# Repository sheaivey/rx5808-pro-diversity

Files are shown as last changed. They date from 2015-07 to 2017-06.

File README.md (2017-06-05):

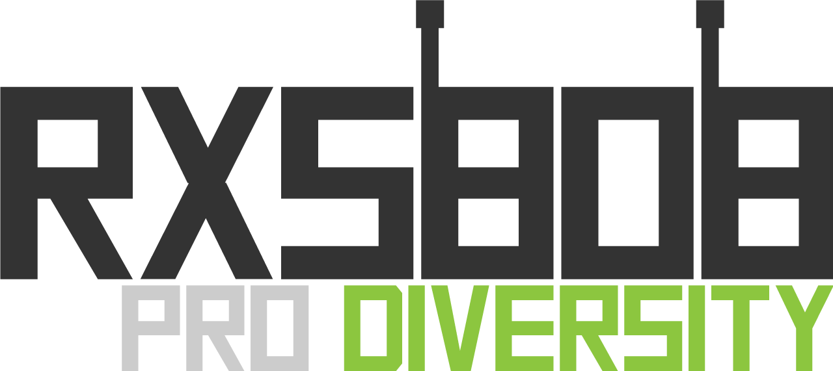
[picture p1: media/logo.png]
# 



This project is a fork of [rx5808-pro](https://code.google.com/p/rx5808-pro/) with support for diversity and much more.

Manufactured version of this project can be found at [La Forge FPV](http://www.laforgefpv.com)

The code is also backward compatible with the original rx5808-pro schematic minus diversity, dip switch mode and TV_Out. For details on updating click [here](/docs/diy-arduino-nano.md).

# Table of Contents
1. [Releases](#releases)
2. [Features](#features)
3. [Overview](#overview)
4. [Hardware](#hardware)
5. [Firmware](#firmware)
6. [Contributing](#contributing)
7. [License](#license)

# Releases
The latest release can be found here. [Latest Releases](https://github.com/sheaivey/rx5808-pro-diversity/releases)

# Features
- **User control** - 3 Button navigation, up, down, select.
- **Manual Mode** - Set channel manual
- **Search Mode** - Search next channel based on RSSI
- **Band Scanner** - Print spectrum of all 48 channels
- **Auto Save** - Saves settings after a few seconds of inactivity.
- **Beeper** - Acoustic feedback on important actions
- **RSSI Graph** - Running history of RSSI readings.
- **Diversity** - Receiver select and monitor.
- **Led Status** - Power, button pressed, active antenna.
- **Race Band & L-Band** - Total of 48 supported channels.
- **Backward Compatibility** - Use this code with your existing setup.
- **OLED Display** - Use a 128x64 OLED.
- **Setup Menu** - Creating changing settings (RSSI Calibration).

# Overview
Please watch the following video giving a detailed overview of the latest v2.0 release.

<p align="center">
    
</p>

1. **Auto Scan** - Scans all bands until a signal with good signal strength is found.
2. **Manual Mode** - Will hold on a manually selected channel.
3. **Band Scanner** - Scans all bands and presents them with a signal strength bar graph.
5. **Settings Menu** - Saves last used channel and mode for next power cycle. This is also where you enter RSSI calibration mode.
    1. **Calibrate RSSI** - Calibrate the min and max RSSI values.

#### Initial Setup
When powering on for the first time it is best to calibrate your RSSI modules. No two modules have the same RSSI min and max readings. To calibrate follow these steps below. You can repeat this process as many times as needed.

1. Go to the settings menu and follow the calibrate RSSI steps on the screen.

# Hardware
#### Manufactured
If you are not looking to build your own hardware you can purchase manufactured versions from the following companies.

1. **[La Forge FPV](http://www.laforgefpv.com/vrx-pro)** - VRX-PRO
  - Designed by Shea Ivey
  - All Current Hardware versions.
2. Realacc - rx5808-pro-diversity
  - All current hardware versions.
3. FuriousFPV - True-D
  - V2.0 and earlier

#### DIY

This project is centered around the RX5808 5.8GHz receiver module which can be found at a number of online stores. The original rx5808-pro schematic has been modified to incorporate the diversity setup. Additional LEDs have also been added to show the active receiver.

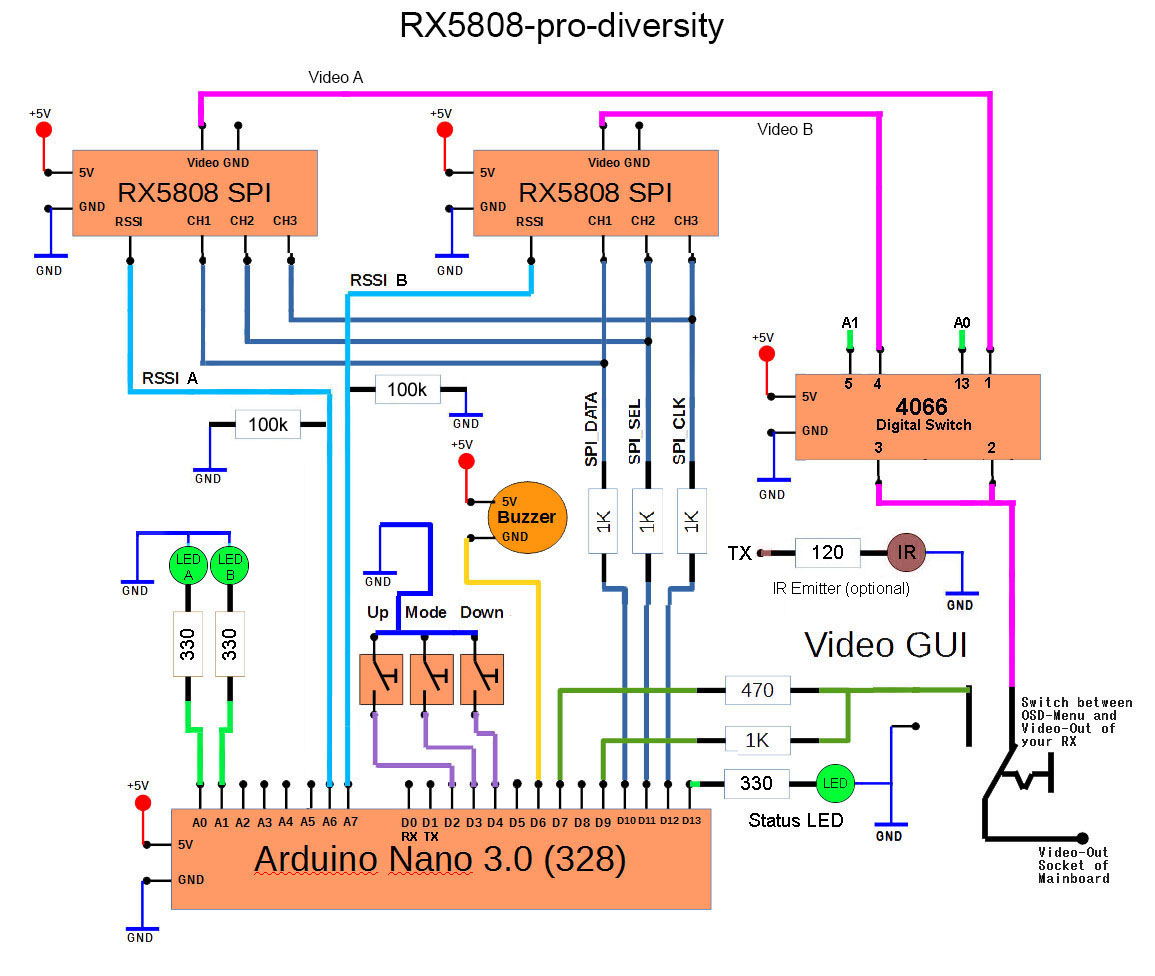
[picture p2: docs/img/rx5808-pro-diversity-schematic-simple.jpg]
diversity simple schematic


For more information on specific hardware implementations:

1. [DIY Simple - Arduino Nano](/docs/diy-arduino-nano.md)
1. [DIY Intermediate - Custom Board (T-Box)](/docs/diy-through-hole-board.md)
2. [DIY Advanced - Custom Board](/docs/diy-custom-board.md)
1. [OLED Version - Arduino Nano](/docs/oled-arduino-nano.md)
3. [rx5808 SPI modification](/docs/rx5808-spi-mod.md)
6. [Voltage Monitoring](/docs/voltage-monitoring.md)

# Firmware
The firmware is constantly being improved please refer to the release history for more detailed information on improvements.
[Release History](https://github.com/sheaivey/rx5808-pro-diversity/releases)

# Contributing
Any contributions are welcome!

Please follow [CONTRIBUTING.md](CONTRIBUTING.md) for standard practices regarding this repo.

## Recognition
- SPI driver based on fs_skyrf_58g-main.c Written by Simon Chambers
- TVOUT by Myles Metzel
- Scanner by Johann Hermen (der-Frickler.net)
- Initial 2 Button version by Peter (pete1990)
- Refactored and GUI reworked by Marko Hoepken
- Universal version my Marko Hoepken
- Diversity Receiver Board and GUI improvements by Shea Ivey
- Adding Race Band by Shea Ivey
- Separating Display concerns for TVOut and OLED by Shea Ivey
- Adding Setup Menu by Shea Ivey
- DIY Throughole board and documentation. by RCDaddy
- Voltage monitoring by kabturek
- v2.0 Firmware Overhaul by @Knifa

# License
## Code
The code is distrubuted under the [MIT license](LICENSE.md).

## Logo
The logo is distributed under the [Creative Commons Attribution 4.0 International](http://creativecommons.org/licenses/by/4.0/) license.

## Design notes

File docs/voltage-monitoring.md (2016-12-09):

#Voltage Monitoring
You can monitor voltages of the attached battery by using any of the arduino analog pins and a voltage divider to lower the voltage to safe levels (5v). You have to enable (uncomment) "#define USE_VOLTAGE_MONITORING" and change "#define VBAT_PIN A2" to the pin you will be using.

Lets take the [DIY Advanced - Custom Board](/docs/diy-custom-board.md) as an example. Atmega 328 has 8 analog inputs (or 6 if youre using the DIP package) - A4 and A5 are used for controlling the oled if you're using one, A6 and A7 are used for measuring RSSI. There are no more easily accesible analog pins on the advanced board - you will have to solder a wire directly to the processor pins. The default pin depends on the screen output - A2 for oled ( on the edge of atmega chip - easier to hand solder) or A4 when TVout is used - use pad SDA on custom board.

Now you have to create a simple voltage divider circuit - let's assume a 3S battery (12.6V max) and use standard resistor values - using R1 = 5.6K and R2 = 3.3K will allow us to connect a battery with voltage of around 13.4V (keep in mind the resistors have 5% tolerance so it's good to have some margin). The cap is optional - it will smooth the voltage readings.
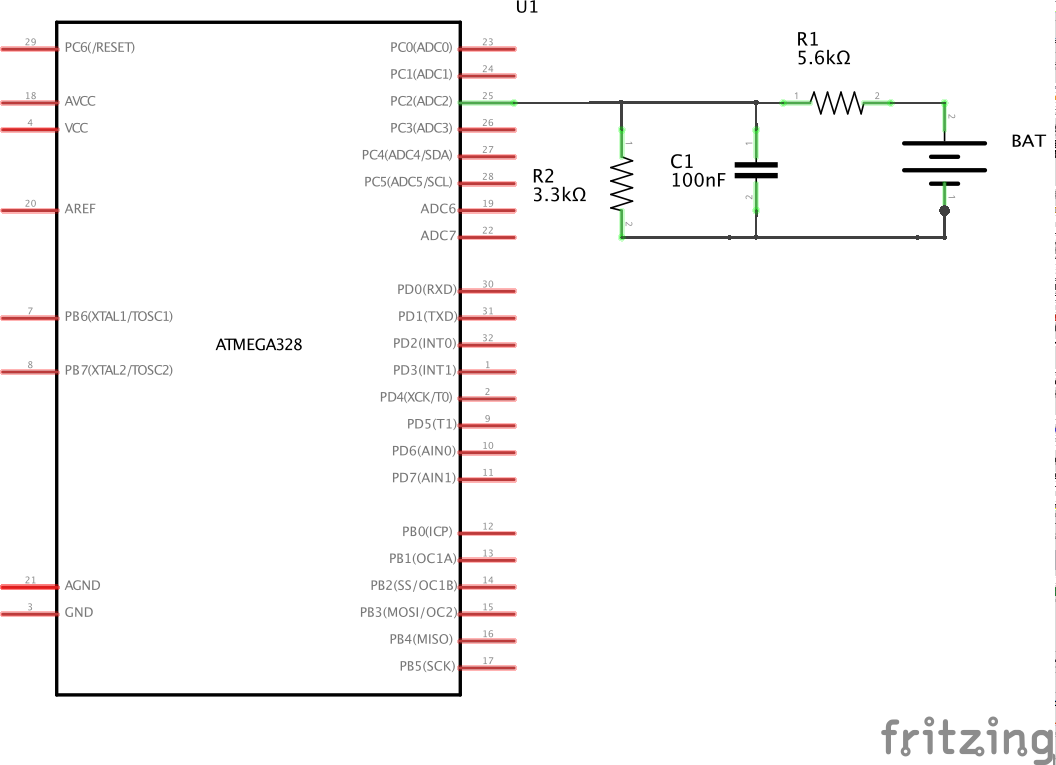
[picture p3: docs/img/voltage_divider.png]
voltage divider


Here is a picture of a voltage divider on the advanced board using an OLED:
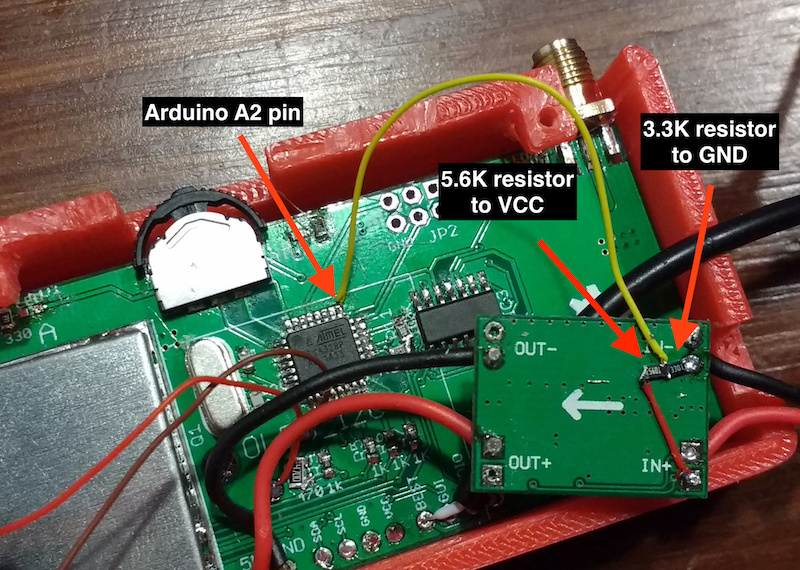
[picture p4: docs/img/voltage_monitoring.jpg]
voltage divider


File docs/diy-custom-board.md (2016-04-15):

#DIY Advanced - Custom Board
This requires ordering a board from [https://oshpark.com/shared_projects/7J17i6at](https://oshpark.com/shared_projects/7J17i6at)
No bootloader is nessissary with this board. Program the board using the SPI breakout pins. (Select Arduino Pro Mini 5v 328 as the board)

####BOM
- 4x 1K ohm resistor 0805 [Mouser](http://www.mouser.com/Search/ProductDetail.aspx?R=ERJ-6ENF1001Vvirtualkey66720000virtualkey667-ERJ-6ENF1001V)
- 1x 470 ohm resistor 0805 [Mouser](http://www.mouser.com/Search/ProductDetail.aspx?R=ERJ-6ENF4700Vvirtualkey66720000virtualkey667-ERJ-6ENF4700V)
- 3x 330 ohm resistor 0805 [Mouser](http://www.mouser.com/Search/ProductDetail.aspx?R=ERJ-6ENF3300Vvirtualkey66720000virtualkey667-ERJ-6ENF3300V)
- 2x 100k ohm resistor 0805 [Mouser](http://www.mouser.com/Search/ProductDetail.aspx?R=ERJ-6ENF1003Vvirtualkey66720000virtualkey667-ERJ-6ENF1003V)
- 2x 22pf capacitor 0805 [Mouser](http://www.mouser.com/Search/ProductDetail.aspx?R=C0805C220J5GACTUvirtualkey64600000virtualkey80-C0805C220J5G)
- 1x 16.0000mhz crystal [Mouser](http://www.mouser.com/Search/ProductDetail.aspx?R=FOXSLF%2f160-20virtualkey55910000virtualkey559-FOXS160-20-LF)
- 2x rx5808 receiver with [spi mod](rx5808-spi-mod.md)
- 2x Blue LEDs 0805 [Mouser](http://www.mouser.com/Search/ProductDetail.aspx?R=LTST-C170KRKTvirtualkey57820000virtualkey859-LTST-C170KRKT)
- 1x Red LED 0805 [Mouser](http://www.mouser.com/Search/ProductDetail.aspx?R=LTST-C170TBKTvirtualkey57820000virtualkey859-LTST-C170TBKT)
- 1x [Navigation switch](https://www.sparkfun.com/products/8184) or [ebay](http://www.ebay.com/itm/231618098407?ul_noapp=true)
- 2x SMA Connector [Mouser](http://www.mouser.com/search/ProductDetail.aspx?R=0virtualkey0virtualkey132322)
- 1x 4066D SO14 digital switch chip SMD [Mouser](http://www.mouser.com/Search/ProductDetail.aspx?R=74LVC4066D%2c118virtualkey66800000virtualkey771-74LVC4066D-T)
- 1x MEGA 328P TQFP [Mouser](http://www.mouser.com/search/ProductDetail.aspx?R=0virtualkey0virtualkeyATMEGA328P-AU)
- 1x Active Buzzer (Optional)
- 1x OLED 128x64 display I2C (5v tollerant) (Optional - If you don't want to do TV_Out)

[Mouser cart](http://www.mouser.com/ProjectManager/ProjectDetail.aspx?AccessID=9f6e677f02) with everything but rx5808, navigation switch and optional parts.

####Schematic
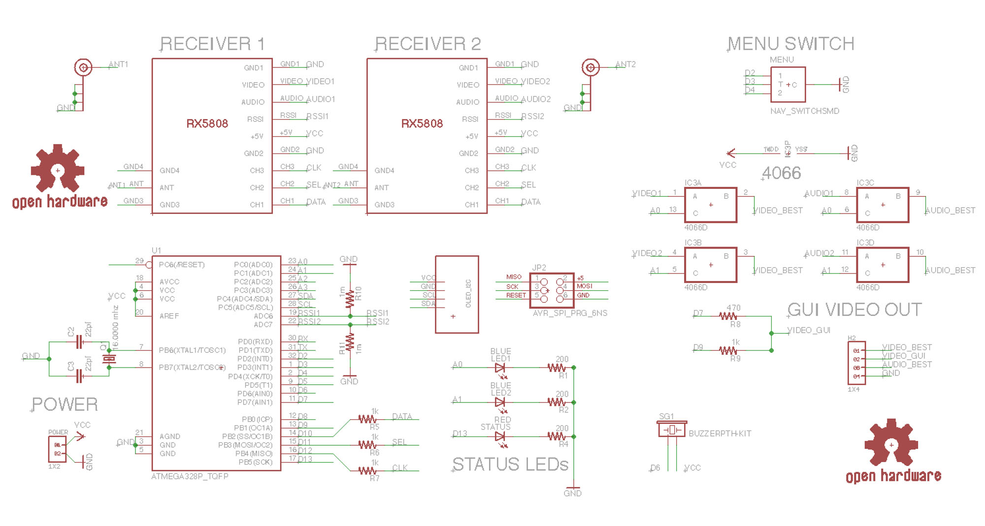
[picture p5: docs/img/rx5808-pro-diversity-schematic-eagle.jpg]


####Board
Silk:
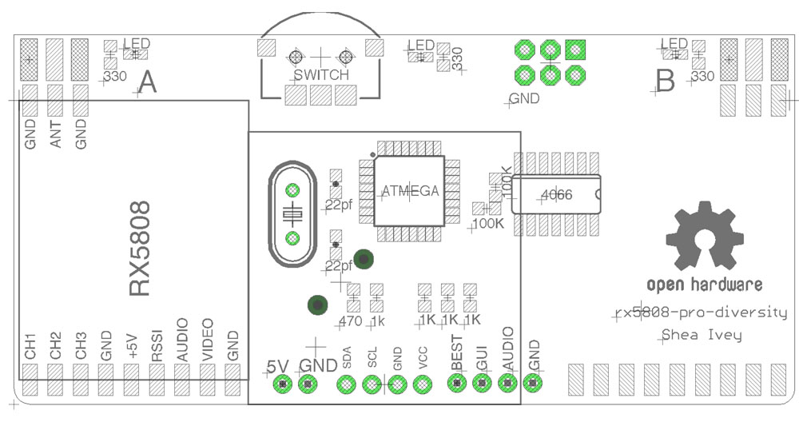
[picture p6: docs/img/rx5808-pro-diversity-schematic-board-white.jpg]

Top:
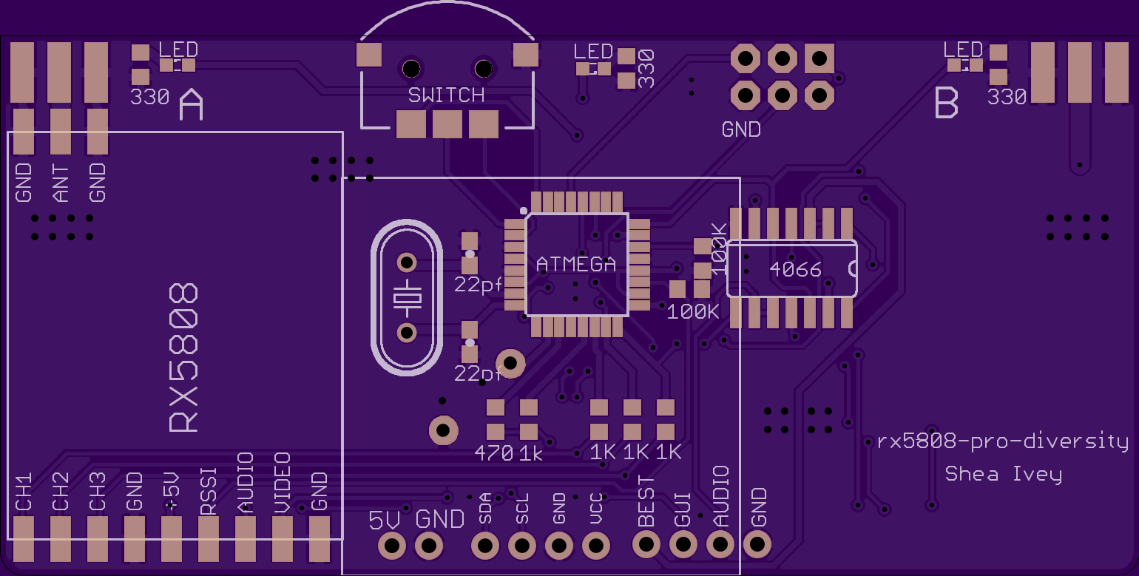
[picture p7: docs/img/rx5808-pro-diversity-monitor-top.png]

Bottom:
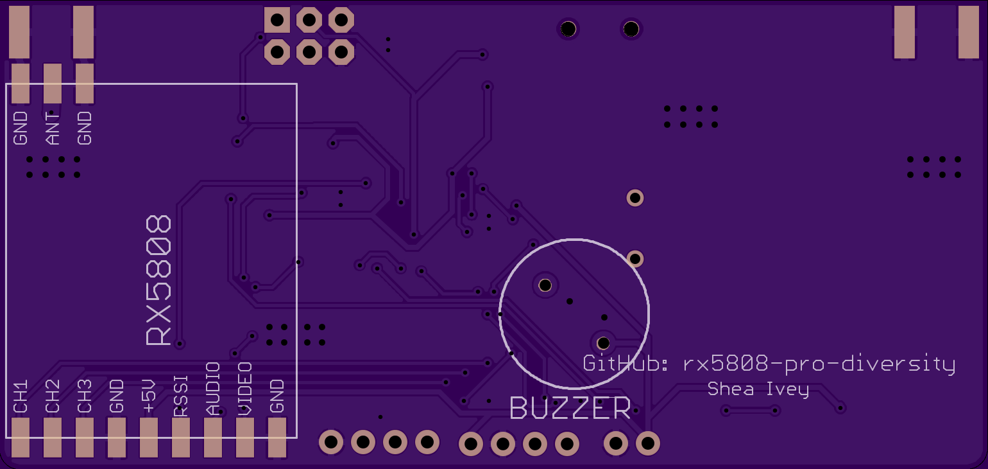
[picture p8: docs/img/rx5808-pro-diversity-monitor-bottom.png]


####Example
Below is an example of the board installed into a 7" monitor. This board will also fit into a 5" monitor. There are two outputs one for the currently active rx5808 module. The other is the GUI that from the ATMEGA 328 chip.

This monitor has two inputs and a source button on the front for switching between the video signals. If your monitor does not allow for two inputs you can use a toggle switch to acheive the same result.
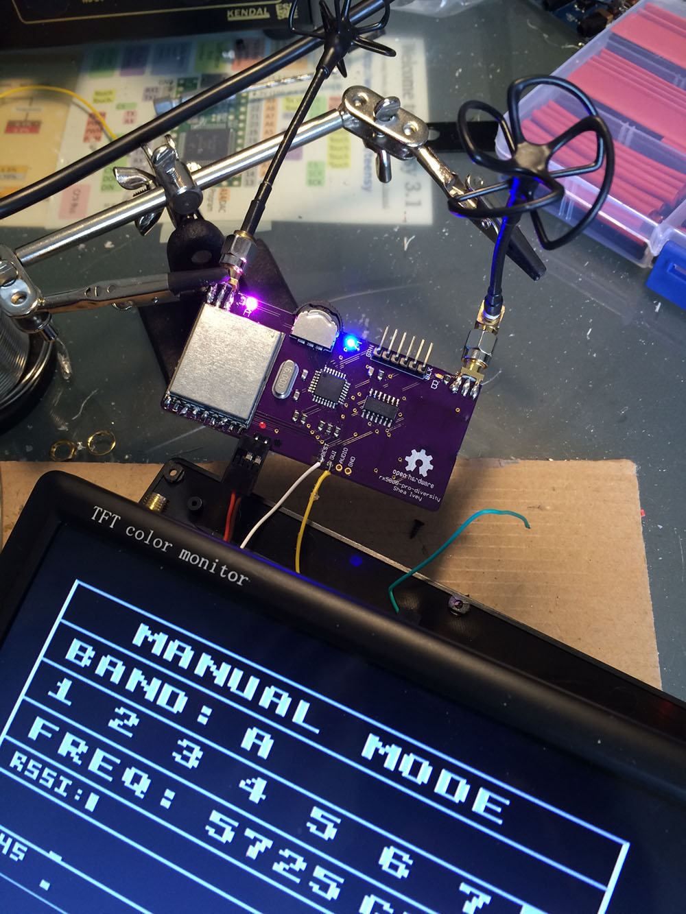
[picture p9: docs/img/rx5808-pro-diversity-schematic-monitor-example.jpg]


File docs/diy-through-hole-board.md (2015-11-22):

#T-Box v1.1 rev 2
Throughhole version of PCB using an Atmega328P chip.

#Source Code
In the settings.h file you will need to change the following lines
```
#define rssiPinA A6
```
to
```
#define rssiPinA A2
```

and also

```
    #define rssiPinB A7
```
to
```
    #define rssiPinB A3
```

####BOM
- 3x 1k resistor
- 2x 100k resistor
- 3x 330 resistor
- 2x rx5808 receiver with [spi mod](rx5808-spi-mod.md)
- 3x 5mm LEDs
- 3x Miniature Tactile Button (9.5mm high if using T-Box enclosure)
- 1x DSN-MIN-360 Step Down regulator.
- 2x RP-SMA/SMA connector board mountable
- 1x 4066 digital switch chip
- 1x Atmega328p (WITH ARDUINO BOOTLOADER!!)
- 1x 16.000Mhz Crystal
- 2x 22pf Cap
- 1x 0.1uf Cap
- 1x 10k resistor
- 1x OLED 128x64 display I2C (5v tollerant) Pin order must be VCC GND SCL SDA

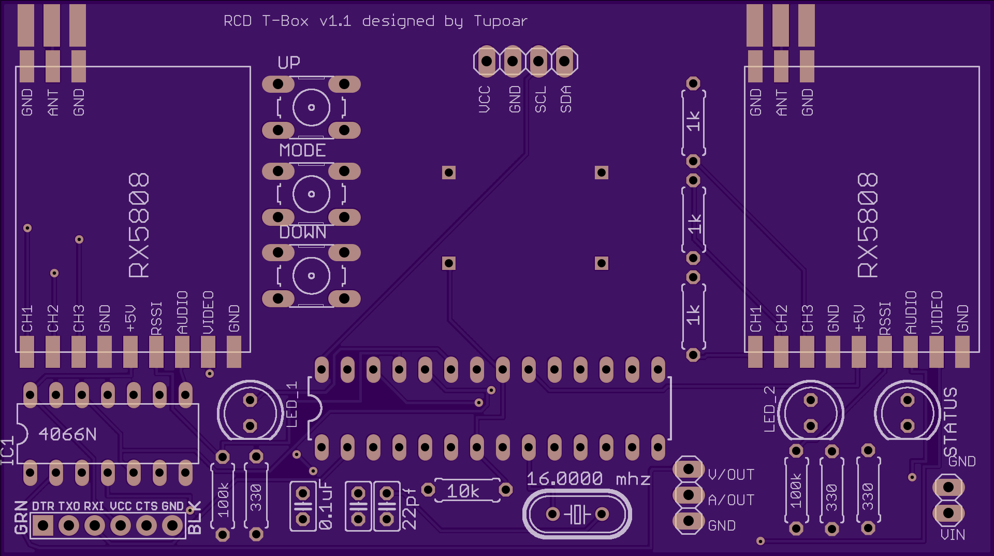
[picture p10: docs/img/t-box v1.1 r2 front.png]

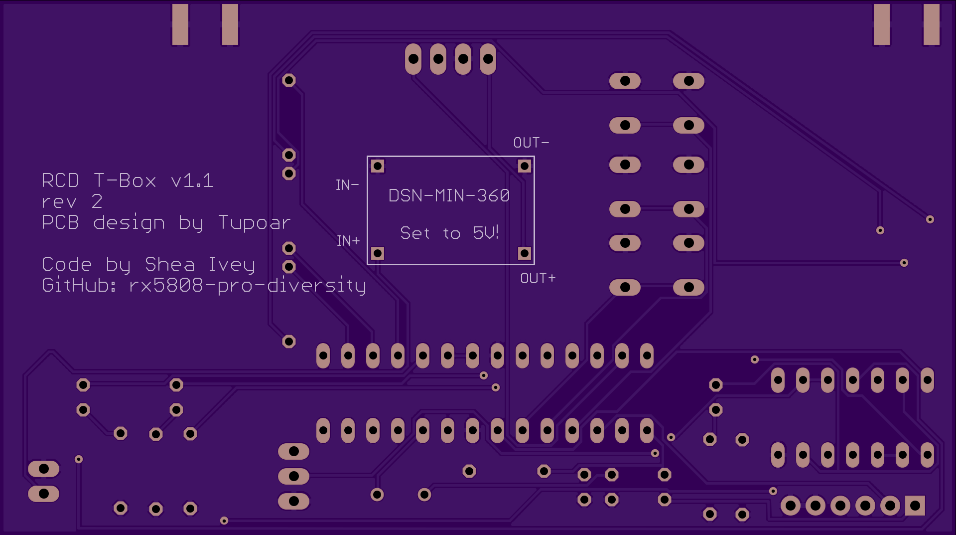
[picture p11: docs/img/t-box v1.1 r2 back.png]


Board available at [OSHPark](https://oshpark.com/shared_projects/U8csRbMR)

#T-Box v1.0 rev 4
Throughhole version of PCB using an Arduino Pro Mini

####BOM
- 3x 1k resistor
- 2x 100k resistor
- 3x 330 resistor
- 2x rx5808 receiver with [spi mod](rx5808-spi-mod.md)
- 3x 5mm LEDs
- 3x Miniature Tactile Button (9.5mm high if using T-Box enclosure)
- 1x DSN-MIN-360 Step Down regulator.
- 2x RP-SMA/SMA connector board mountable
- 1x 4066 digital switch chip
- 1x Arduino Pro Mini
- 1x OLED 128x64 display I2C (5v tollerant) Pin order must be VCC GND SCL SDA

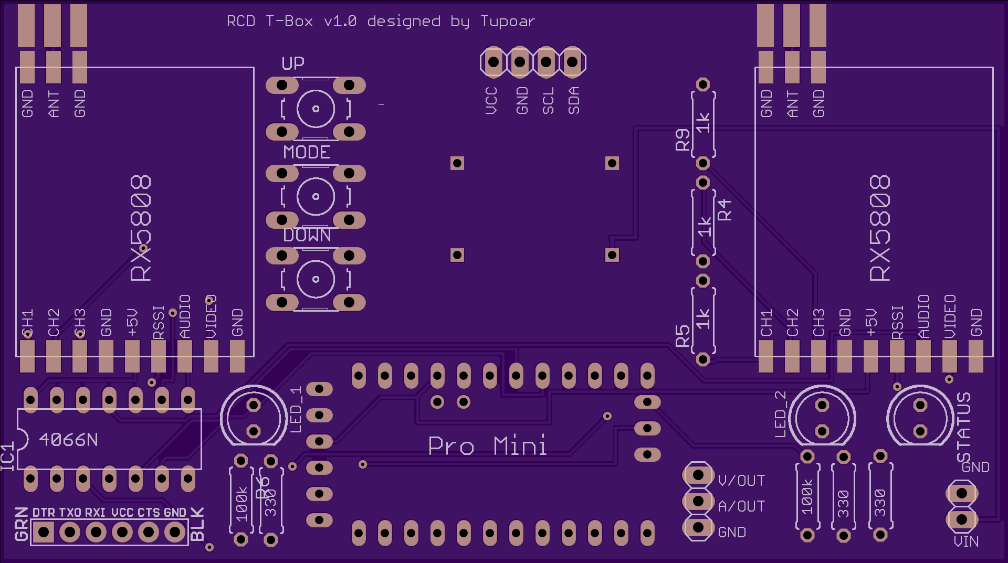
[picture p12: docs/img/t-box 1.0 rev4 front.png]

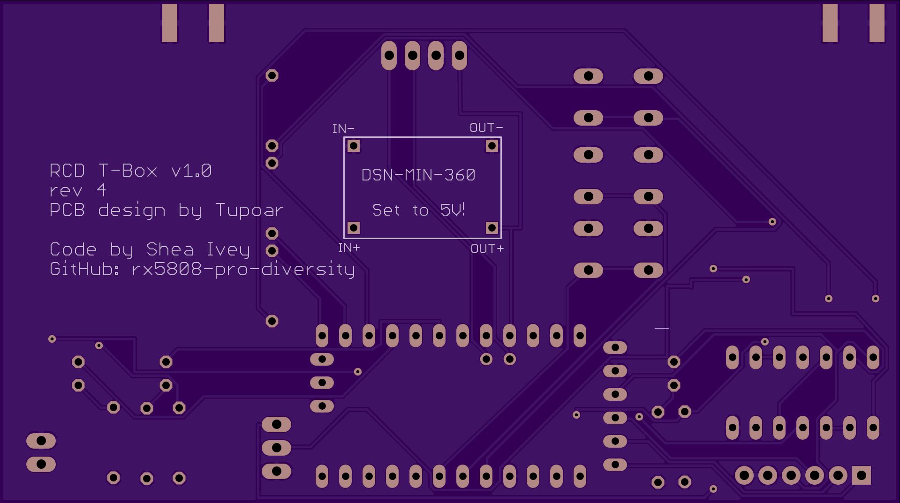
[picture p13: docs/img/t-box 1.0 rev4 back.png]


Board available at [OSHPark](https://oshpark.com/shared_projects/0Lq0DYFU)

Schematics and enclosure can be found at [T-Box](https://github.com/RCDaddy/T-Box)

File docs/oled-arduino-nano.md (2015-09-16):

#OLED Screen Shots
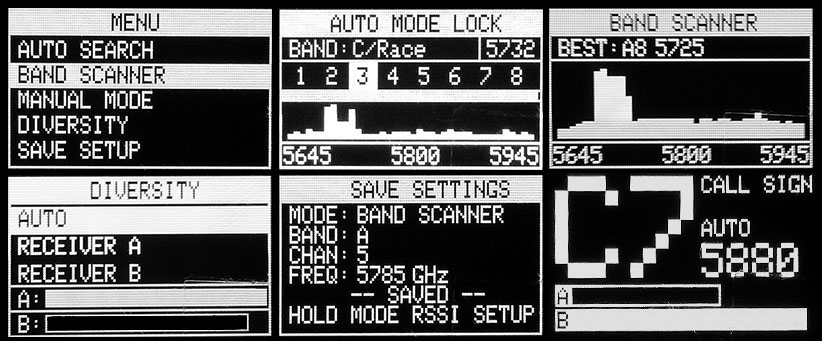
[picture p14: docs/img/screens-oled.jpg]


Below is a quick video demonstration the performance of the I2C OLED display.
Video (http://www.youtube.com/watch?v=I4wZWitvHXw)

#Source Code
[Code](../src/rx5808-pro-diversity/rx5808-pro-diversity.ino)
You will need the following Adafruit libraries:
```
Adafruit_SSD1306.h
Adafruit_GFX.h
```

In the settings.h file uncomment the following line OLED_128x64_ADAFRUIT_SCREENS
```
// Choose the display you will be using
// you will also have to uncomment the includes in the main project.
//#define TVOUT_SCREENS
#define OLED_128x64_ADAFRUIT_SCREENS
```
NOTE: only one screen can be use at a time.

In the main project uncomment the following lines
```
// uncomment depending on the display you are using.
// this is an issue with the arduino preprocessor
#ifdef TVOUT_SCREENS
//    #include <TVout.h>
//    #include <fontALL.h>
#endif
#ifdef OLED_128x64_ADAFRUIT_SCREENS
    #include <Adafruit_SSD1306.h>
    #include <Adafruit_GFX.h>
    #include <Wire.h>
    #include <SPI.h>
#endif
```

Make sure the you have selected the correct screen size in Adafruit_SSD1306.h
```
#define SSD1306_128_64
//   #define SSD1306_128_32
//   #define SSD1306_96_16
```

You may need to change the following line to be the correct I2C address for your OLED display. Found in
[here](../src/rx5808-pro-diversity/oled_128x64_adafruit_screens.cpp)
```
display.begin(SSD1306_SWITCHCAPVCC, 0x3C);  // initialize with the I2C addr 0x3D (for the 128x64)
```

#OLED Diversity - Arduino Nano

####BOM
- 3x 1k resistor
- 3x 330 resistor
- 2x rx5808 receiver with [spi mod](rx5808-spi-mod.md)
- 3x LEDs
- 3x Momentary switch
- 1x Toggle switch
- 1x Buzzer (optional)
- 1x 4066 digital switch chip
- 1x Arduino Nano 3.0 328
- 1x OLED 128x64 display I2C (5v tollerant)

####Schematic
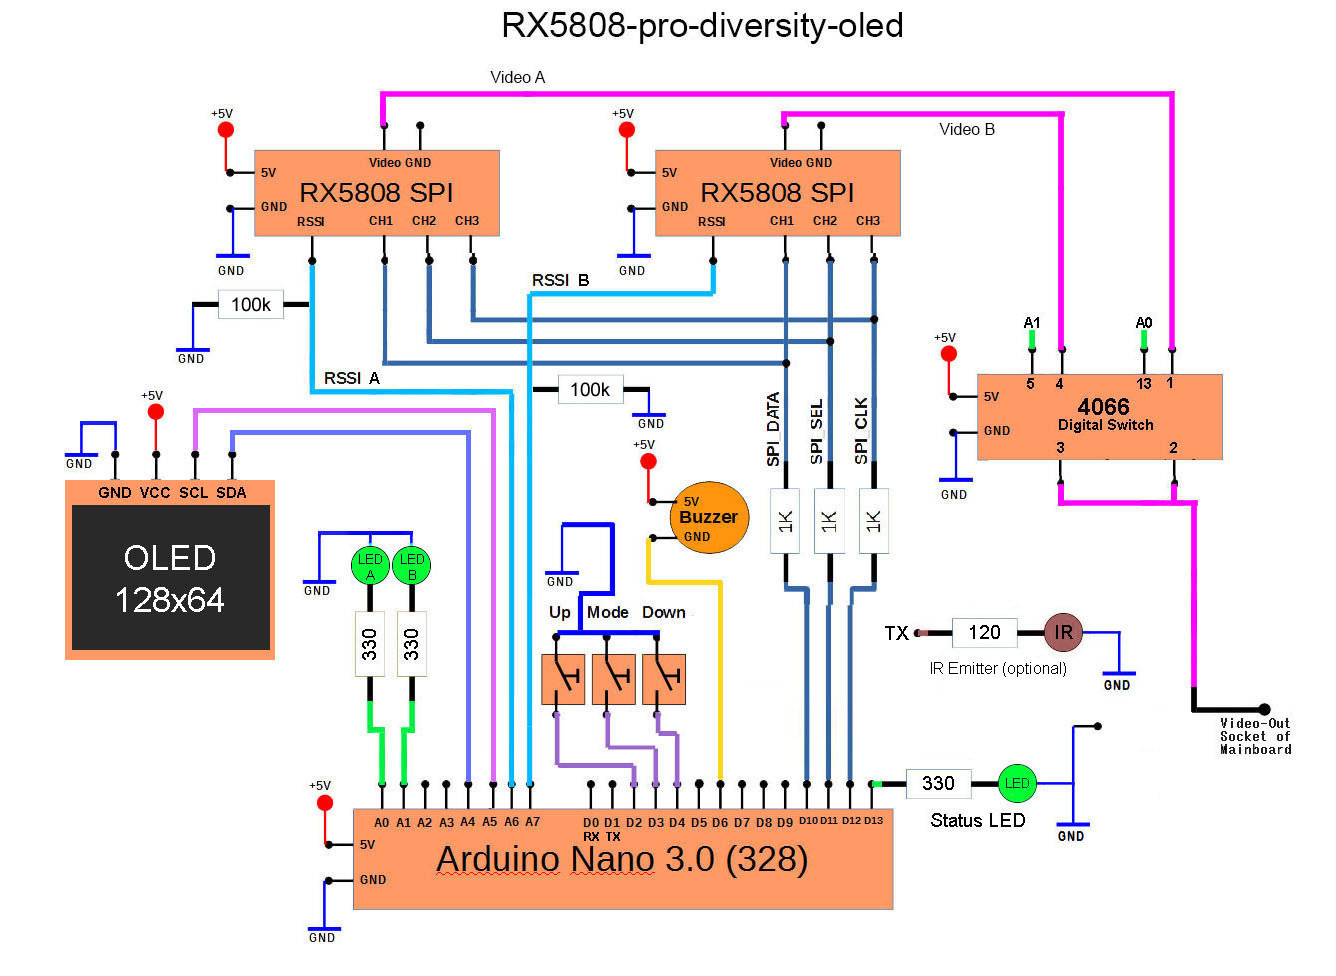
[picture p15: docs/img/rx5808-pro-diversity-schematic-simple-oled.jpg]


#OLED Basic - Arduino Nano (Not Diversity)
You can comment out the following line to remove the diversity menu from the GUI. (Note: dip mode is still not implemented.)
```
#define USE_DIVERSITY
```

####BOM
- 3x 1k resistor
- 1x 330 resistor (optional)
- 1x rx5808 receiver with [spi mod](rx5808-spi-mod.md)
- 1x LEDs (optional)
- 3x Momentary switch
- 1x Toggle switch
- 1x Buzzer (optional)
- 1x Arduino Nano 3.0 328
- 1x OLED 128x64 display I2C (5v tollerant)

####Schematic
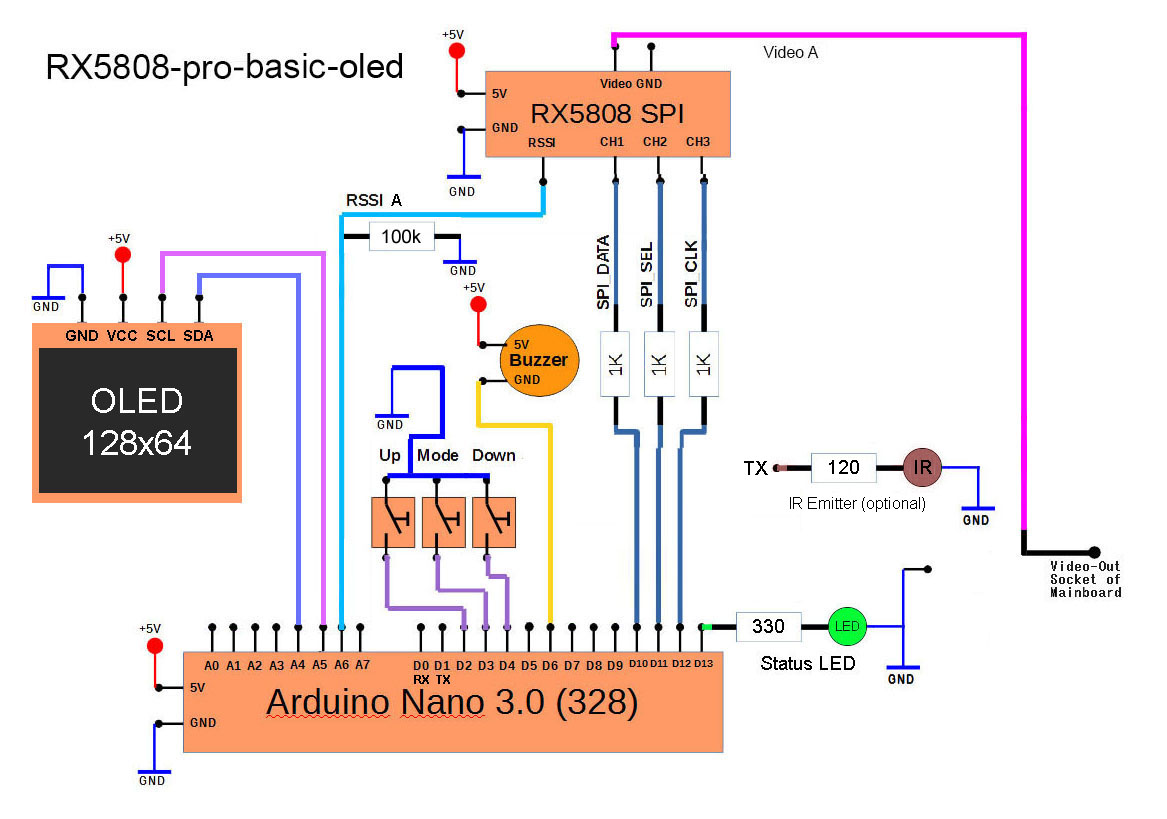
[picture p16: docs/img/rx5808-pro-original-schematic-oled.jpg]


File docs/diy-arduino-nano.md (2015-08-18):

#DIY Simple - Arduino Nano

####BOM
- 4x 1k resistor
- 1x 470 resistor
- 3x 330 resistor
- 2x rx5808 receiver with [spi mod](rx5808-spi-mod.md)
- 3x LEDs
- 3x Momentary switch
- 1x Toggle switch
- 1x Buzzer (optional)
- 1x 4066 digital switch chip
- 1x Arduino Nano 3.0 328

####Schematic


#DIY Basic - Arduino Nano (Not Diversity)
You can comment out the following line to remove the diversity menu from the GUI. (Note the dip mode is still not implemented.)
```
#define USE_DIVERSITY
```

####BOM
- 4x 1k resistor
- 1x 470 resistor
- 1x 330 resistor (optional)
- 1x rx5808 receiver with [spi mod](rx5808-spi-mod.md)
- 1x LEDs (optional)
- 3x Momentary switch
- 1x Toggle switch
- 1x Buzzer (optional)
- 1x Arduino Nano 3.0 328

####Schematic
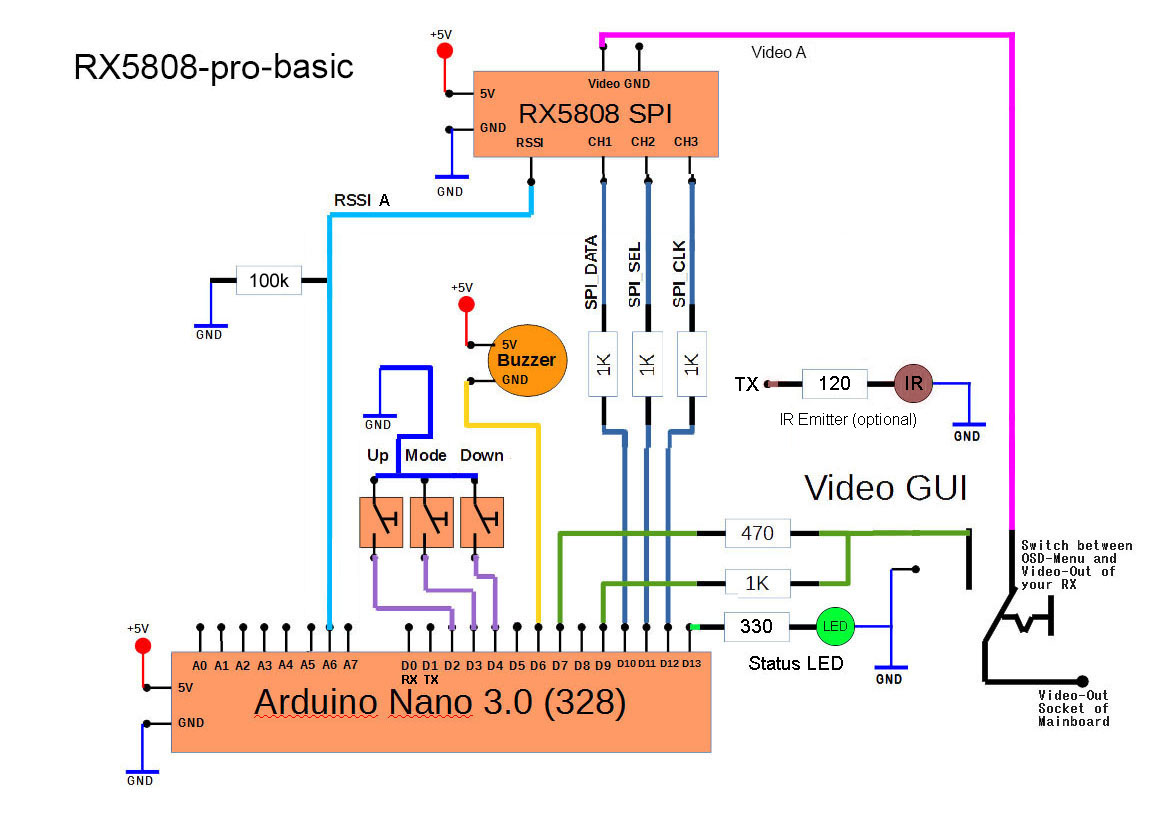
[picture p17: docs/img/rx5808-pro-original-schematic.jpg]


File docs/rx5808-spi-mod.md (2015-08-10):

#rx5805 SPI modification
In order to get the rx5808 to use SPI you will need to open it and remove a single SMD resistor.

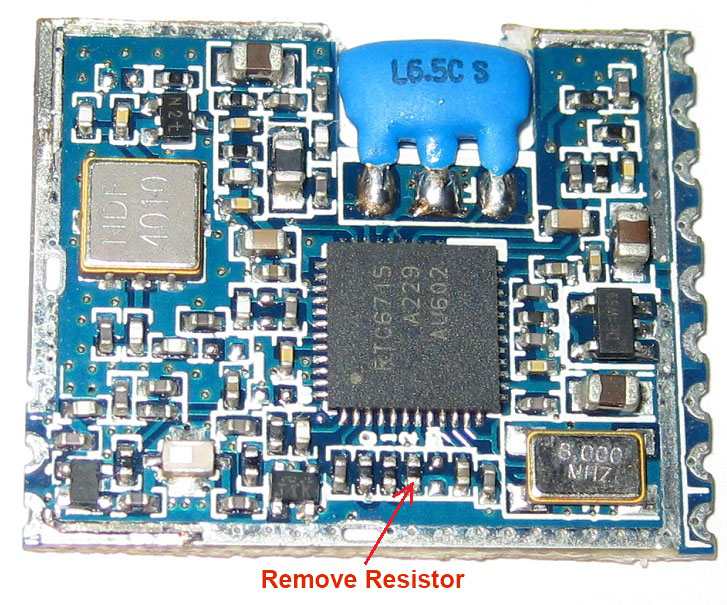
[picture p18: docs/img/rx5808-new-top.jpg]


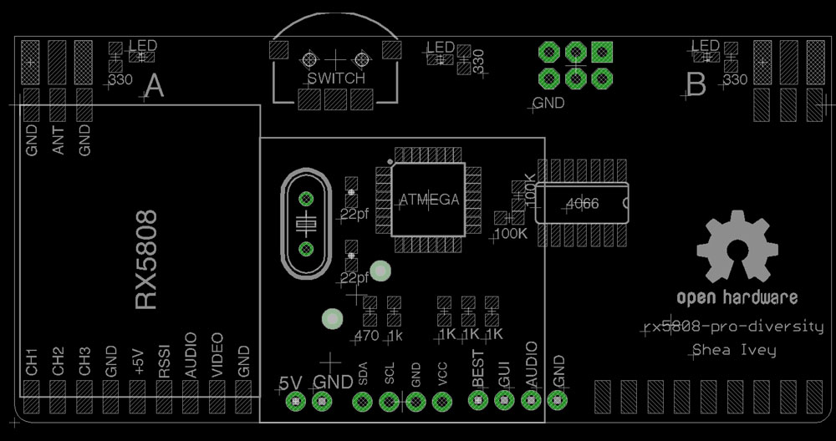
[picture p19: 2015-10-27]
docs/img/rx5808-pro-diversity-schematic-board.jpg

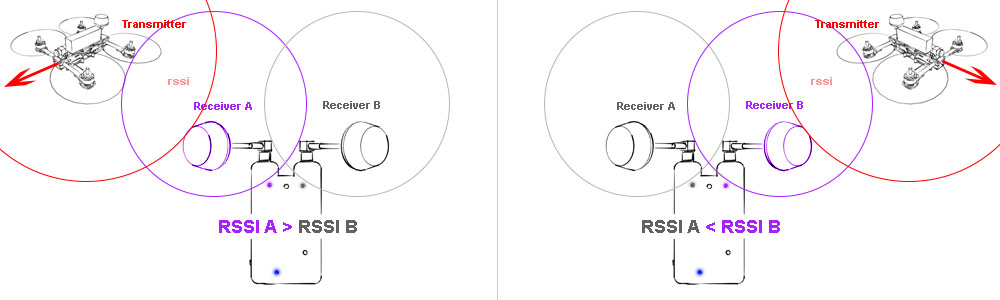
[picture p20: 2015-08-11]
docs/img/diversity-example.jpg

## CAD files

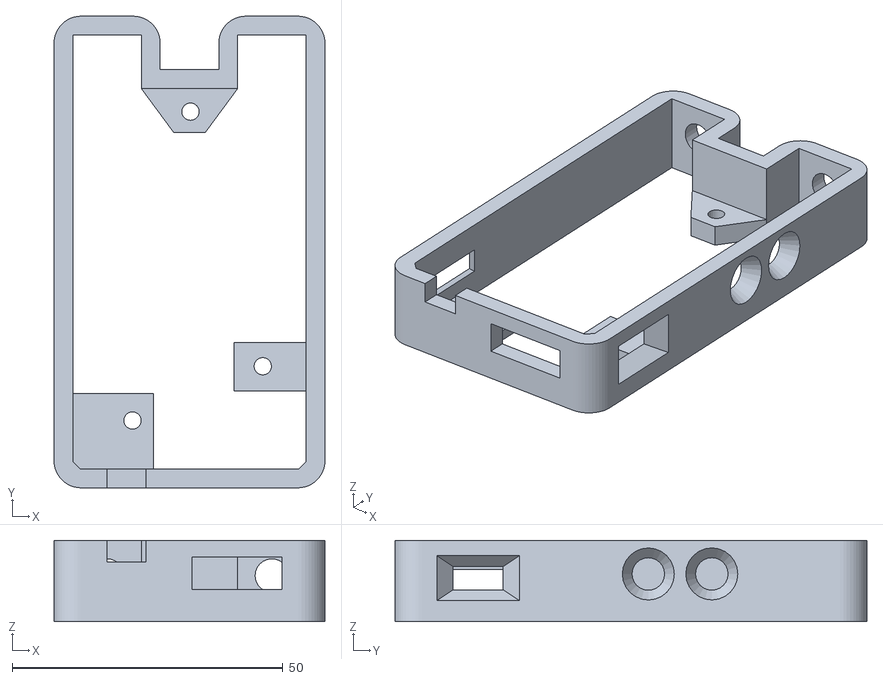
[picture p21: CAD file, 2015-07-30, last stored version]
enclosure/enclosure-wall.stl
50.0 x 87.0 x 15.0

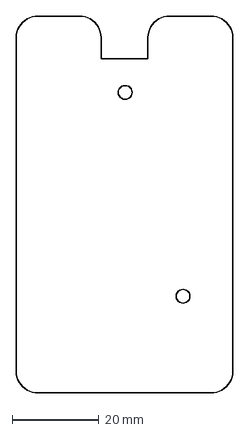
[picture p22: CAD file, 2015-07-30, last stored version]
enclosure/enclosure-lines.dxf
50.0 x 87.0 mm

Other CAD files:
enclosure/enclosure.skp
enclosure/enclosure~.skp

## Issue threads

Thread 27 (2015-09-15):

Add pulldown resistor to RSSI.

sheaivey, 2015-09-15:
In the event a receiver looses power or RSSI gets disconnected this will ensure there are no floating pins on the ATMEGA. This will make sure the other receiver fails over quickly.

nathantsoi, 2015-09-29:
Building one of these now, any suggestions on how strong to make the pulldown. Seems like 10k might be appropriate?

sheaivey, 2015-09-29:
I'm using 100k. A 10k allowed to much current to flow to ground and the atmega received a very weak RSSI voltage.

100k does not mess with the overall RSSI signal very much but does give a true low when RSSI is disconnected.

Good luck with your build!

nathantsoi, 2015-09-29:
Awesome, 100k it is. Nice work w/ this project. I'm stoked to get mine running.

sheaivey, 2015-10-05:
I have updated all the images to include the RSSI pulldown resistor.

Closed 2015-10-05.

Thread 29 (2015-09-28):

Make it "tri", "quad" or more diversity ?

yoannwyffels, 2015-09-28:
Would it be possible to have, 3, 4, or more connected in order to use patch or directionnal antennas ?

Hasi123, 2015-09-28:
Even antenna tracking could be implemented. Two directional and one Omni antenna.

sheaivey, 2015-09-28:
How the code is currently written it can only support two receivers at them moment. However the ATMEGA328 chip has two more free analog pins. So in theory it could support a 4 receiver diversity setup.

If the need for this is there, the best plan of action would be to make an a few arrays that handle all the rssi concerns such as:
```
// define the number if receivers
define #RECEIVER_COUNT 4
rssi_pins[RECEIVER_COUNT] = {A6,A7,A2,A3}; // what analog pin each receiver sits on
rssi_max[RECEIVER_COUNT] = {0,0,0,0}; // for calibration of each receiver
rssi_min[RECEIVER_COUNT] = {255,255,255,255}; // for calibration of each receiver
//... and so on
```
Now the diversity concerns of the code would be based on the RECEIVER_COUNT

I'll leave this open incase someone else wants to take this on.

yoannwyffels, 2015-09-29:
Thanks Sheaivey :)
Some peoples from "Airgonay" - a famous French FPV club - successfully design a triversity (and even a quadversity), you can take a look at (in french sorry): http://www.airgonay.com/forums/showthread.php?4042-vol-FPV-racing-en-5-8G-combien-de-pilots/page34

and some nice pictures of their first prototype (with 4 directionnal antennas !):
http://www.airgonay.com/forums/showthread.php?4042-vol-FPV-racing-en-5-8G-combien-de-pilots/page17

But they use a PI5V331 IC to switch video (seems very fast according to their tests, they push the switch to 50hz without any video flickers). Does the 4066 digital switch you're using will accept more than 2 video sources ?

sheaivey, 2015-09-29:
@yoannwyffels Thanks for the info on their diversity project. That PI5V331 IC is pretty impressive. However it is about $1.25 more expensive then the 4066 IC.
in comparison the PI5V331 seems to have a faster switching (10ns vs 20ns) action but out side of that they function pretty similar.

The 4066 IC can also control 4 inputs just like the PI5V331. As far as switching is concerned flickering can come from many things...
1. For example one receiver may not output the same brightness as its siblings from the same manufacture.
2. Another cause of flicker is how fast the receiving monitor can adjust to the ~20ns gap in signal.
Those issues will cause a flicker regardless of how good the video switching is.

Because of that the 4066D chips are more then adequate for the task and at a substantially cheaper cost.

Another reason to choose the 4066D is that it can switch any signal such as audio and is not limited to only switching video sources. How I set up my diversity circuits video and audio are switched.

You can also find the larger version of this digital switch as well. I think they come in 2,4,8 versions.

yoannwyffels, 2015-09-30:
PI5V331 also have a lower internal resistance. I'm not sure about consequences, and even if 4066 IC is working great, a "PI5V331" version will be better :)
Regarding audio, where do you get it ? I can't find any audio "out" in RX5808 diagram ? Maybe A6.5M out ?

sheaivey, 2015-09-30:
Yeah, give it a try with the PI5V331! I may try it myself with future builds.

You are correct about A6.5. That should be all you need to connect for audio out.

Closed 2016-03-02.

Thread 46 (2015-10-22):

Up/Down button presses are reversed in some screens.

sheaivey, 2015-10-22:

sheaivey, 2015-11-05:
This has been fixed.

Closed 2015-11-05.

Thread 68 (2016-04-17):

RSSI problem

Kordiss, 2016-04-17:
I made it single rx with OLED. I also comment out diversity mode but rssi strength not shown correctly. Calibration is done. rssi signal is moving to top when you move tx nearby about 5-10cm . I also try every kind of antennas. Any idea ?

Kordiss, 2016-04-23:
I double checked my hardware and I found that rx5808 has 2 kind of version pcb. Mine is an old and spi patch should to be drill. Other new versions are you should to remove resistor. Problem resolved.

Closed 2016-04-23.

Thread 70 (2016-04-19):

channelTable error for raceband

bluesign2k, 2016-04-19:
I believe that there is a typo on the channel table for raceband - specifically channel c5.
The current value is 0x2978, however I believe this will be setting a frequency of 5967 Mhz rather than the 5806 that it is supposed to be. I believe that the correct value should be 0x2987.

sheaivey, 2016-08-01:
This has been fixed. https://github.com/sheaivey/rx5808-pro-diversity/pull/80

Closed 2016-08-01.

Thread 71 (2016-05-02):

cannot compile non-adafruit oled code with arduino 1.6.8

vcazan, 2016-05-02:
Hey im trying to compile the non adafruit display version and I keep getting this error, any advise?

"C:\Program Files (x86)\Arduino\tools-builder\ctags\5.8-arduino10/ctags" -u --language-force=c++ -f - --c++-kinds=svpf --fields=KSTtzns --line-directives "C:\Users\Vlad\AppData\Local\Temp\build63c49c85898a371be4a35fbd0f3cefff.tmp\preproc\ctags_target_for_gcc_minus_e.cpp"
Using previously compiled file: C:\Users\Vlad\AppData\Local\Temp\build63c49c85898a371be4a35fbd0f3cefff.tmp\sketch\TVOut_screens.cpp.o
Using previously compiled file: C:\Users\Vlad\AppData\Local\Temp\build63c49c85898a371be4a35fbd0f3cefff.tmp\sketch\oled_128x64_adafruit_screens.cpp.o
"C:\Program Files (x86)\Arduino\hardware\tools\avr/bin/avr-g++" -c -g -Os -w -std=gnu++11 -fno-exceptions -ffunction-sections -fdata-sections -fno-threadsafe-statics -MMD -mmcu=atmega328p -DF_CPU=16000000L -DARDUINO=10608 -DARDUINO_AVR_PRO -DARDUINO_ARCH_AVR   "-IC:\Program Files (x86)\Arduino\hardware\arduino\avr\cores\arduino" "-IC:\Program Files (x86)\Arduino\hardware\arduino\avr\variants\eightanaloginputs" "-IC:\Program Files (x86)\Arduino\hardware\arduino\avr\libraries\EEPROM\src" "-IC:\Users\Vlad\Documents\Arduino\libraries\U8glib\src" "-IC:\Users\Vlad\Documents\Arduino\libraries\TVout" "-IC:\Users\Vlad\Documents\Arduino\libraries\TVoutfonts" "C:\Users\Vlad\AppData\Local\Temp\build63c49c85898a371be4a35fbd0f3cefff.tmp\sketch\oled_128x64_u8g_screens.cpp" -o "C:\Users\Vlad\AppData\Local\Temp\build63c49c85898a371be4a35fbd0f3cefff.tmp\sketch\oled_128x64_u8g_screens.cpp.o"
oled_128x64_u8g_screens.cpp:53: error: prototype for 'char screens::begin()' does not match any in class 'screens'

 char screens::begin() {

      ^

In file included from C:\Users\Vlad\AppData\Local\Temp\build63c49c85898a371be4a35fbd0f3cefff.tmp\sketch\oled_128x64_u8g_screens.cpp:39:0:

screens.h:50: error: candidate is: char screens::begin(const char*)

         char begin(const char *call_sign);

              ^

oled_128x64_u8g_screens.cpp:116: error: prototype for 'void screens::updateSeekMode(uint8_t, uint8_t, uint8_t, uint8_t, uint16_t, bool)' does not match any in class 'screens'

 void screens::updateSeekMode(uint8_t state, uint8_t channelIndex, uint8_t channel, uint8_t rssi, uint16_t channelFrequency, bool locked) {

      ^

In file included from C:\Users\Vlad\AppData\Local\Temp\build63c49c85898a371be4a35fbd0f3cefff.tmp\sketch\oled_128x64_u8g_screens.cpp:39:0:

screens.h:58: error: candidate is: void screens::updateSeekMode(uint8_t, uint8_t, uint8_t, uint8_t, uint16_t, uint8_t, bool)

         void updateSeekMode(uint8_t state, uint8_t channelIndex, uint8_t channel, uint8_t rssi, uint16_t channelFrequency, uint8_t rssi_seek_threshold, bool locked); // seek and manual mode

              ^

C:\Users\Vlad\AppData\Local\Temp\build63c49c85898a371be4a35fbd0f3cefff.tmp\sketch\oled_128x64_u8g_screens.cpp: In member function 'void screens::updateBandScanMode(bool, uint8_t, uint8_t, uint8_t, uint16_t, uint16_t, uint16_t)':

oled_128x64_u8g_screens.cpp:135: error: 'SCANNER_LIST_X_POS' was not declared in this scope

     static uint8_t writePos=SCANNER_LIST_X_POS;

                             ^

C:\Users\Vlad\AppData\Local\Temp\build63c49c85898a371be4a35fbd0f3cefff.tmp\sketch\oled_128x64_u8g_screens.cpp: At global scope:

oled_128x64_u8g_screens.cpp:139: error: prototype for 'void screens::screenSaver(uint8_t, uint16_t)' does not match any in class 'screens'

 void screens::screenSaver(uint8_t channelName, uint16_t channelFrequency) {

      ^

In file included from C:\Users\Vlad\AppData\Local\Temp\build63c49c85898a371be4a35fbd0f3cefff.tmp\sketch\oled_128x64_u8g_screens.cpp:39:0:

screens.h:66: error: candidates are: void screens::screenSaver(uint8_t, uint8_t, uint16_t, const char*)

         void screenSaver(uint8_t diversity_mode, uint8_t channelName, uint16_t channelFrequency, const char *call_sign);

              ^

screens.h:65: error: void screens::screenSaver(uint8_t, uint16_t, const char*)

         void screenSaver(uint8_t channelName, uint16_t channelFrequency, const char *call_sign);

              ^

oled_128x64_u8g_screens.cpp:142: error: prototype for 'void screens::screenSaver(uint8_t, uint8_t, uint16_t)' does not match any in class 'screens'

 void screens::screenSaver(uint8_t diversity_mode, uint8_t channelName, uint16_t channelFrequency) {

      ^

In file included from C:\Users\Vlad\AppData\Local\Temp\build63c49c85898a371be4a35fbd0f3cefff.tmp\sketch\oled_128x64_u8g_screens.cpp:39:0:

screens.h:66: error: candidates are: void screens::screenSaver(uint8_t, uint8_t, uint16_t, const char*)

         void screenSaver(uint8_t diversity_mode, uint8_t channelName, uint16_t channelFrequency, const char *call_sign);

              ^

screens.h:65: error: void screens::screenSaver(uint8_t, uint16_t, const char*)

         void screenSaver(uint8_t channelName, uint16_t channelFrequency, const char *call_sign);

              ^

oled_128x64_u8g_screens.cpp:163: error: prototype for 'void screens::save(uint8_t, uint8_t, uint16_t)' does not match any in class 'screens'

 void screens::save(uint8_t mode, uint8_t channelIndex, uint16_t channelFrequency) {

      ^

In file included from C:\Users\Vlad\AppData\Local\Temp\build63c49c85898a371be4a35fbd0f3cefff.tmp\sketch\oled_128x64_u8g_screens.cpp:39:0:

screens.h:79: error: candidate is: void screens::save(uint8_t, uint8_t, uint16_t, const char*)

         void save(uint8_t mode, uint8_t channelIndex, uint16_t channelFrequency, const char *call_sign);

              ^

Using library EEPROM at version 2.0 in folder: C:\Program Files (x86)\Arduino\hardware\arduino\avr\libraries\EEPROM
Using library U8glib at version 1.19.1 in folder: C:\Users\Vlad\Documents\Arduino\libraries\U8glib
Using library TVout at version 1.0.1 in folder: C:\Users\Vlad\Documents\Arduino\libraries\TVout
Using library TVoutfonts in folder: C:\Users\Vlad\Documents\Arduino\libraries\TVoutfonts (legacy)
exit status 1
prototype for 'char screens::begin()' does not match any in class 'screens'
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

sheaivey, 2016-05-23:
u8g library was never completed due to library limitations.

vcazan, 2016-05-23:
Good to know, might be worth taking it out from the codebase in master.

Closed 2016-05-23.

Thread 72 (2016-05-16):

rx5808 gets video signal but Arduino Nano does not display RSSI [Double checked connections]

chapimp, 2016-05-16:
I'm not getting RSSI signal with Arduino Nano.

-I know that rx5808 works because I connected to a analog monitor and see video.
-The [A6] pin on the Arduino, I believe it works fine because when I press the pin with my thumb, Arduino starts getting a reading, the harder I press, the higher the reading.

So I'm not sure if it's the rx5808 [rssi] that is not working.
I also tried with a NexWaveRF rx, gets video but no rssi, I found online where the rssi pin was for this rx.

sheaivey, 2016-05-23:
Sounds like an issue with the RX5808 module not outputting RSSI... A good test would be to change the code and try a different analog pin on your nanoClosing this issue as it is more a problem with your hardware and not with the actual project.

Closed 2016-05-23.

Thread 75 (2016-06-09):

More channel table errors for raceband

Dvogonen, 2016-06-09:
There is already a bug report about the spi table error for raceband channel 5. The deviation leads to a huge frequency error in the RTC6715 frequenzy synthesizer (5967MHz set instead of the correct  5806MHz).

I am working on code to directly control the RitchWave RTC6715 circuit and checked my frequency calculation code against the spiValues table in this repository. It turns out that there are four additional errors in the raceband table that each result in a 2MHz frequency deviation. 2 MHz isn't that much, but it is better to be spot on than slightly off.

Current table:

const uint16_t channelTable[] PROGMEM = {
  // Channel 1 - 8
  0x2a05 ,0x299b ,0x2991 ,0x2987 ,0x291d ,0x2913 ,0x2909 ,0x289f ,
  0x2903 ,0x290c ,0x2916 ,0x291f ,0x2989 ,0x2992 ,0x299c ,0x2a05 ,
  0x2895 ,0x288b ,0x2881 ,0x2817 ,0x2a0f ,0x2a19 ,0x2a83 ,0x2a8d ,
  0x2906 ,0x2910 ,0x291a ,0x2984 ,0x298e ,0x2998 ,0x2a02 ,0x2a0c ,
  0x281d ,0x288f ,0x2902 ,0x2914 ,0x2978 ,0x2999 ,0x2a0c ,0x2a1e
}

Corrected table

const uint16_t channelTable[] PROGMEM = {
  // Channel 1 - 8
  0x2a05 ,0x299b ,0x2991 ,0x2987 ,0x291d ,0x2913 ,0x2909 ,0x289f ,
  0x2903 ,0x290c ,0x2916 ,0x291f ,0x2989 ,0x2992 ,0x299c ,0x2a05 ,
  0x2895 ,0x288b ,0x2881 ,0x2817 ,0x2a0f ,0x2a19 ,0x2a83 ,0x2a8d ,
  0x2906 ,0x2910 ,0x291a ,0x2984 ,0x298e ,0x2998 ,0x2a02 ,0x2a0c ,
  0x281d ,0x2890 ,0x2902 ,0x2915 ,0x2987 ,0x299a ,0x2a0c ,0x2a1f
}

pfriedel, 2016-06-10:
So as a cross check, I ran those numbers through the datasheet SPI mode register code (FLO = 2*(N*32+A)*(Fosc/R)) and I get the following tuned frequencies - "calc" is what the N and A values would tune in to, "tgt" is the target for that channel in that band, and whether it's off by one.  I believe the math prohibits from getting any closer than 1mhz off on even numbered frequencies - scanning the alternate tuning options shows they're all off by one.

<pre>
Band A:
hex    calc tgt
0x2a05 5865 5865
0x299b 5845 5845
0x2991 5825 5825
0x2987 5805 5805
0x291d 5785 5785
0x2913 5765 5765
0x2909 5745 5745
0x289f 5725 5725

Band B:
0x2903 5733 5732 off-by-one
0x290c 5751 5752 off-by-one
0x2916 5771 5771
0x291f 5789 5790 off-by-one
0x2989 5809 5809
0x2992 5827 5828 off-by-one
0x299c 5847 5847
0x2a05 5865 5866 off-by-one

Band E:
0x2895 5705 5705
0x288b 5685 5685
0x2881 5665 5665
0x2817 5645 5645
0x2a0f 5885 5885
0x2a19 5905 5905
0x2a83 5925 5925
0x2a8d 5945 5945

Band F:
0x2906 5739 5740 off-by-one
0x2910 5759 5760 off-by-one
0x291a 5779 5780 off-by-one
0x2984 5799 5800 off-by-one
0x298e 5819 5820 off-by-one
0x2998 5839 5840 off-by-one
0x2a02 5859 5860 off-by-one
0x2a0c 5879 5880 off-by-one

Band C / RB:
0x281d 5657 5658 off-by-one
0x2890 5695 5695 (original 0x288f is 5693mhz)
0x2902 5731 5732 off-by-one
0x2915 5769 5769 (original 0x2914 is 5767mhz)
0x2987 5805 5806 off-by-one (original 0x2978 is 5967mhz, I think?)
0x299a 5843 5843 (original 0x2999 is 5841mhz)
0x2a0c 5879 5880 off-by-one
0x2a1f 5917 5917 (original 0x2a1e is 5915mhz)
</pre>

sheaivey, 2016-06-10:
Thanks for the heads up @Dvogonen and @pfriedel. I'm actually looking into this now as well. The equation gives us float values (XXXX.5) however we can only send whole numbers and depending on the round this could leave us off by one or two MHz.

I put together this function a while back however I never fully trusted it to handle float conversions. Right now I'm giving it the full shake down to see how well it performs.
```
// calculate the frequency to bit bang payload
uint16_t freq_to_reg(uint16_t f)
{
    uint16_t tf, N, A;
    tf = (f - 479) / 2;
    N = tf / 32;
    A = tf % 32;
    return (N<<7) + A;
}
```

sheaivey, 2016-06-10:
Using my function i posted above I get about the same results as @pfriedel if I round the result.
```
// Band A
VM454:58 Freq: 5865, Calc: 0x2A05 (0x2A05) GOOD
VM454:58 Freq: 5845, Calc: 0x299B (0x299B) GOOD
VM454:58 Freq: 5825, Calc: 0x2991 (0x2991) GOOD
VM454:58 Freq: 5805, Calc: 0x2987 (0x2987) GOOD
VM454:58 Freq: 5785, Calc: 0x291D (0x291D) GOOD
VM454:58 Freq: 5765, Calc: 0x2913 (0x2913) GOOD
VM454:58 Freq: 5745, Calc: 0x2909 (0x2909) GOOD
VM454:58 Freq: 5725, Calc: 0x289F (0x289F) GOOD
VM454:51
// Band B
VM454:58 Freq: 5733, Calc: 0x2903 (0x2903) GOOD
VM454:58 Freq: 5752, Calc: 0x290D (0x290C) OFF BY 1
VM454:58 Freq: 5771, Calc: 0x2916 (0x2916) GOOD
VM454:58 Freq: 5790, Calc: 0x2920 (0x291F) OFF BY 1
VM454:58 Freq: 5809, Calc: 0x2989 (0x2989) GOOD
VM454:58 Freq: 5828, Calc: 0x2993 (0x2992) OFF BY 1
VM454:58 Freq: 5847, Calc: 0x299C (0x299C) GOOD
VM454:58 Freq: 5866, Calc: 0x2A06 (0x2A05) OFF BY 1
VM454:51
// Band E
VM454:58 Freq: 5705, Calc: 0x2895 (0x2895) GOOD
VM454:58 Freq: 5685, Calc: 0x288B (0x288B) GOOD
VM454:58 Freq: 5665, Calc: 0x2881 (0x2881) GOOD
VM454:58 Freq: 5645, Calc: 0x2817 (0x2817) GOOD
VM454:58 Freq: 5885, Calc: 0x2A0F (0x2A0F) GOOD
VM454:58 Freq: 5905, Calc: 0x2A19 (0x2A19) GOOD
VM454:58 Freq: 5925, Calc: 0x2A83 (0x2A83) GOOD
VM454:58 Freq: 5945, Calc: 0x2A8D (0x2A8D) GOOD
VM454:51
// Band F / Airwave
VM454:58 Freq: 5740, Calc: 0x2907 (0x2906) OFF BY 1
VM454:58 Freq: 5760, Calc: 0x2911 (0x2910) OFF BY 1
VM454:58 Freq: 5780, Calc: 0x291B (0x291A) OFF BY 1
VM454:58 Freq: 5800, Calc: 0x2985 (0x2984) OFF BY 1
VM454:58 Freq: 5820, Calc: 0x298F (0x298E) OFF BY 1
VM454:58 Freq: 5840, Calc: 0x2999 (0x2998) OFF BY 1
VM454:58 Freq: 5860, Calc: 0x2A03 (0x2A02) OFF BY 1
VM454:58 Freq: 5880, Calc: 0x2A0D (0x2A0C) OFF BY 1
VM454:51
// Band C / Immersion Raceband
VM454:58 Freq: 5658, Calc: 0x281E (0x281D) OFF BY 1
VM454:58 Freq: 5695, Calc: 0x2890 (0x288F) OFF BY 1
VM454:58 Freq: 5732, Calc: 0x2903 (0x2902) OFF BY 1
VM454:58 Freq: 5769, Calc: 0x2915 (0x2914) OFF BY 1
VM454:58 Freq: 5806, Calc: 0x2988 (0x2987) OFF BY 1
VM454:58 Freq: 5843, Calc: 0x299A (0x2999) OFF BY 1
VM454:58 Freq: 5880, Calc: 0x2A0D (0x2A0C) OFF BY 1
VM454:58 Freq: 5917, Calc: 0x2A1F (0x2A1E) OFF BY 1
```
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
Dvogonen, 2016-06-19:
Hi, I just checked back in to see how things where moving here.
I notice that you are trying to increase the precision of the receiver by changing the frequency divisor in SYN_RF-R_REG. I thought of that myself, but gave up on the idea since I came to the conclusion that it would not work. The frequency calculation according to the data sheet:
2(N*32+A)*(Fosc/R) + 479
The problem is that all calculations are on integers, not floats.
Whichever way you change N, A and R the result of (N*32+A)(Fosc/R) can only become an integer. This is then multiplied with with 2 and 479 is added.
The circuit is simply not capable of using even frequencies. You will always end up with an odd result.

sheaivey, 2016-06-24:
Your assumption of the TX having the same issue is incorrect. The equation to set the channel on the VTX deals in KHz without a base frequency. This means the transmitter is capable of having a much finer tune and will land on even or odd without floating point.

```
FRF = 2*(N*64+A)*(Fosc/R)
FRF=5865MHz, Fosc=8MHz, R=400
￼5865=(2*N*64+A)*8Mhz/400=2*(N*64+A)*20
N=2291(=8F3xH), A=1(=01xH)
```

---

Back to the RX side of things if we were able to set the SYN_RF_R_REG to 0x10 (16) we would be able to hit the frequency dead on... even or odd. this is because the 0.5 floating point calculations happen to land us exactly on whole numbers when the frequency is even.

```
2*(N*32+A)*(Fosc/R) + 479
2*(N*32+A)*(8/16) + 479
2*(N*32+A)*(.5) + 479

// Odd example
N=168, A=10
2*(168*32+10)*(.5) + 479 = 5865

// Even example
N=168, A=11
2*(168*32+11)*(.5) + 479 = 5866
```

I reached out to the company who makes the chip and they suggested using 480 as the base frequency but just reverses the problem making us only able to land on even tune, making odd frequencies off by 1.

We are so close it would be unfortunate to give up now. **The only problem I am having is sending the command to set SYN_RF_R_REG to 0x10 (16)**

Dvogonen, 2016-06-24:
You are right. My mistake was that I did not think of the fact that the result of the frequency division will not become 0.5. It is instead 500000 since the circuit is dividing 8MHz with 16 and get 0.5MHz=500000Hz. And the division is not really a mathematical division, it is an instruction to ignore a specified number of clock ticks.

I have got no really good idea why you can not set the divider to 0x10. The data sheet is very hard to understand. First it says that 0x10 is the default, then it goes on to say that 0x08 is the default. Strange.

Have you tried writing the register several consecutive times? Or writing and reading the register in cycle a number of times ? The reason I ask is that I think I have seen intermittent failures to set channel values. The failures are not repeatable and only seem to occur the first time a channel value is written. The following writes succeed. But this is only speculations. I have not verified my observations.

sheaivey, 2016-06-25:
No worries @Dvogonen I have had a hard time trying to understand the data sheet as well. I'm going to take your suggestion and try sending the command a few times back to back. Hopefully that is all the issue is. I'll also double check all my calculations and make sure I'm sending everything right.

Side note, I was looking over your CYCLOP+ project and like where you are going with it. Should be a good improvement for the Quantums.

Dvogonen, 2016-06-25:
I am traveling and do not have access to my equipment, otherwise I would have made an attempt at writing the register out of curiosity.

I will anyhow write code to verify that writing the channel setting register work. I have only seen what I suspect where failed writes twice. Hopefully I am wrong.

Thank you for your kind words on CYCLOP+. Using your project as inspiration and a source of information made an extreme difference when I wrote the CYCLOP+ code.

sheaivey, 2016-08-01:
This issue is deeper within the RTC6705 chips protocol not accepting certain SPI commands.

Closed 2016-08-01.

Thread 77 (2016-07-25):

rx5808 pro dual diversity  with the nano

buckrogers1, 2016-07-25:
Hi everyone . Im an ex missile tech. ,and am building the receiver, rx5808 pro dual diversity  with the nano .Can you guys connect me with build pictures? Ive been looking for two weeks and I cant seem to figure out the Git Hub .I got the boards from ohpark, have the nanos and all other parts . I want to build the model without the oled ,ill use a regular monitor . A picture of the top and bottom before and after the nano is installed . How long of extensions can the antennae connectors have on them for base station mounting before signal loss . When we first turn this on , do I need to paste and include some code into the arduino sketch library? All I read for directions were the parts list ,something about removing a part on each rx , and something about calibrating signal strength . There is code stuff all over but nothing seemingly directed at the nano version. It sure would be nice just to follow a recipe ,build the board , set up this ,do that, now you ready to go . Any help out there ?

zanthor, 2016-07-25:
> How long of extensions can the antennae connectors have on them for base
station mounting before signal loss.

Not long at all!  Anything over 6" and you start losing signal quickly.

On Mon, Jul 25, 2016 at 3:48 PM buckrogers1 <notifications@github.com>
wrote:

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

buckrogers1, 2016-07-25:
Well thanks but it makes it kind of tough for if you want to hide cables for external antennae . I have the nano board version dual rx5808 and the parts list doesnt match the schematic and neither match the board  i got 3 of .My board has a group of resistors mounted on opposite side of board from nano ,2 leds. the nano has to be mounted on opposite side of board from rx to match pinout  i think . And Im also looking at the 15 db gain antennaes ,thinking this might cure the signal loss problem . This is all from the sheaivy site but Im too new to be able to find simple procedures for this or its not ther and not supposed to be . A little please . Oh by the way , my name is ken

sheaivey, 2016-07-25:
@buckrogers1 I'm not sure which board you are referring to? None of the purple boards from OshPark use the Arduino Nano.

The through-hole version boards use an Arduino Pro Mini @ 5v. you can find documentation on those boards here.
https://github.com/sheaivey/rx5808-pro-diversity/blob/master/docs/diy-through-hole-board.md

The only board that supports GUI Video Out to a monitor is the custom advanced board.
https://github.com/sheaivey/rx5808-pro-diversity/blob/master/docs/diy-custom-board.md

Since it sounds like you are new to the Arduino world I suggest brushing up on some of the basics centered around uploading firmware to the MCU. You can also read more about this project over at the RCGroups thread.
http://www.rcgroups.com/forums/showthread.php?t=2477752

You are more then welcome to submit a pull request with updated documentation once you get things running.

-Shea

buckrogers1, 2016-07-25:
diy simple arduino nano rx 5808 pro diversity ,Im looking at it now in another window . yes I do need to learn arduino and i will . . Did I get the wrong board  for a nano build ?It has a place for two leds by the antennae jacks , 15 resistors in a row between  a 19 dip and room for 2 rx5808, and a 4066 chip. What do I have ?Id like to go nanno .Im pretty sure i ordered this as a nanno board Im sure the documentation said it was the same as another board except it uses a nanno .I will try to find that comment . Meanwhile I need to sort this out and maybe i messed up but well see .

    On Monday, July 25, 2016 3:14 PM, Shea Ivey <notifications@github.com> wrote:

 @buckrogers1 I'm not sure which board you are referring to? None of the purple boards from OshPark use the Arduino Nano.The through-hole version boards use an Arduino Pro Mini @ 5v. you can find documentation on those boards here.
https://github.com/sheaivey/rx5808-pro-diversity/blob/master/docs/diy-through-hole-board.mdThe only board that supports GUI Video Out to a monitor is the custom advanced board.
https://github.com/sheaivey/rx5808-pro-diversity/blob/master/docs/diy-custom-board.mdSince it sounds like you are new to the Arduino world I suggest brushing up on some of the basics centered around uploading firmware to the MCU. You can also read more about this project over at the RCGroups thread.
http://www.rcgroups.com/forums/showthread.php?t=2477752You are more then welcome to submit a pull request with updated documentation once you get things running.-Shea—
You are receiving this because you were mentioned.
Reply to this email directly, view it on GitHub, or mute the thread.

buckrogers1, 2016-07-25:
https://oshpark.com/shared_projects/Y2Zlih1f       This is the one and my apoligies for being a rookie but i really want to build this so help me out if you can .

buckrogers1, 2016-07-26:
rx5808 Nano Board copy

 Top Bottom
2 layer board of 3.94x1.54 inches (100.00x39.01 mm).
Uploaded on July 13th, 2016 18:02.
Previous orders:

Ordered on July 13th, 2016 (SHIPPED) View order.
Half the height, all the fun. Ok, only 15mm out of 54, but it’s an important 15mm. Only change to the BOM is an Arduino Nano replacing a Pro Micro. Some quality of life improvements to the layout, but nothing significant.

buckrogers1, 2016-07-26:
OSH Park ~ rx5808 Nano Board

|
|
|
|   |    |

   |

  |
|
|   |
OSH Park ~ rx5808 Nano Board
   |   |

  |

  |

 rx5808 Nano Board copyTop Bottom
2 layer board of 3.94x1.54 inches (100.00x39.01 mm). 
Uploaded on July 13th, 2016 18:02. 
Previous orders:Ordered on July 13th, 2016 (SHIPPED) View order.
Half the height, all the fun. Ok, only 15mm out of 54, but it’s an important 15mm. Only change to the BOM is an Arduino Nano replacing a Pro Micro. Some quality of life improvements to the layout, but nothing significant. this is from oh park shared projects and the board is a red mixed with blue closely resembling "purple"

    On Monday, July 25, 2016 4:01 PM, Kenneth l Wagner <kennethlwagner@yahoo.com> wrote:

 diy simple arduino nano rx 5808 pro diversity ,Im looking at it now in another window . yes I do need to learn arduino and i will . . Did I get the wrong board  for a nano build ?It has a place for two leds by the antennae jacks , 15 resistors in a row between  a 19 dip and room for 2 rx5808, and a 4066 chip. What do I have ?Id like to go nanno .Im pretty sure i ordered this as a nanno board Im sure the documentation said it was the same as another board except it uses a nanno .I will try to find that comment . Meanwhile I need to sort this out and maybe i messed up but well see .

    On Monday, July 25, 2016 3:14 PM, Shea Ivey <notifications@github.com> wrote:

 @buckrogers1 I'm not sure which board you are referring to? None of the purple boards from OshPark use the Arduino Nano.The through-hole version boards use an Arduino Pro Mini @ 5v. you can find documentation on those boards here.
https://github.com/sheaivey/rx5808-pro-diversity/blob/master/docs/diy-through-hole-board.mdThe only board that supports GUI Video Out to a monitor is the custom advanced board.
https://github.com/sheaivey/rx5808-pro-diversity/blob/master/docs/diy-custom-board.mdSince it sounds like you are new to the Arduino world I suggest brushing up on some of the basics centered around uploading firmware to the MCU. You can also read more about this project over at the RCGroups thread.
http://www.rcgroups.com/forums/showthread.php?t=2477752You are more then welcome to submit a pull request with updated documentation once you get things running.-Shea—
You are receiving this because you were mentioned.
Reply to this email directly, view it on GitHub, or mute the thread.

sheaivey, 2016-07-26:
@buckrogers1 I have not seen that board before but it is using the Arduino Nano. The nano and 4066 chips are mounted on the opposite side as the RX modules. Aside from using through hole components the build will be the same as the rest of the boards. I would suggest looking for more information on this board from where ever you found it from.

That is about all I can help with. When you finish I suggest creating a new documentation page and list out the build procedure you had to do to get this board working. Then do a PR to add it to this repo so others can have a better starting point.

-Shea

buckrogers1, 2016-07-27:
Ok ,So oh park lists resisitor as the person , my  lead .I will find the documentation if its there , maybe. But if its almost the same except for the nano substitution ,then I just have to include the code files into the arduino sketch library ,and maybe modify the code depending which model ,then check it with sketch, then upload to board . Right? I have to make a repository for my sketch to put copies of the masters you guys make in.  Waitin for the rain ,im an organic mushroom picker from oregon 

    On Tuesday, July 26, 2016 10:07 AM, Shea Ivey <notifications@github.com> wrote:

 @buckrogers1 I have not seen that board before but it is using the Arduino Nano. The nano and 4066 chips are mounted on the opposite side as the RX modules. Aside from using through hole components the build will be the same as the rest of the boards. I would suggest looking for more information on this board from where ever you found it from.That is about all I can help with. When you finish I suggest creating a new documentation page and list out the build procedure you had to do to get this board working. Then do a PR to add it to this repo so others can have a better starting point.-Shea—
You are receiving this because you were mentioned.
Reply to this email directly, view it on GitHub, or mute the thread.

Closed 2016-12-13.

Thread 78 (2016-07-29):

rx5808  dual diversity nano board

buckrogers1, 2016-07-29:
https://oshpark.com/shared_projects/Y2Zlih1f        I have this board version , of the rx 5808 dual diversity receiver using the nano . I have contacted osh park , sheaivy ,patrick , pfriedel and the closet i got was a red board that had some things in common with my version but not the same build at all . I have the purple rx 5808 nano board version that I had to purchase 3 of , and Ive been putting a couple hours a day for 2 weks now into finding the correct build info , no luck . Can you guys find the correct build docs. for the osh park nano board and send me a link please . Im rather new to github and rc forum  but someone else should be able to find this easier than me . Youd think osh park having sold me the boards from their shared projects would be able to connect me with a thousand other people but not yet .

buckrogers1, 2016-07-30:
https://cloud.githubusercontent.com/assets/20030826/17267545/e27ed14c-55c0-11e6-8873-4f28722bef9e.jpg
https://cloud.githubusercontent.com/assets/20030826/17267565/47f9c554-55c1-11e6-8ba1-0337250ea5ec.jpg

buckrogers1, 2016-07-30:
This what i have so far ,dont know where this is really supposed to go but its something

sheaivey, 2016-07-30:
Looks like you are well on your way! Keep it up. From what I have heard in the forums it is an pretty much the same as all the other throughhole builds.

sheaivey, 2016-08-01:
closing this issue as it is a duplicate of issue #77
https://github.com/sheaivey/rx5808-pro-diversity/issues/77

Closed 2016-08-01.

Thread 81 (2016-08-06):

Noisy OSD Menu Screen

whirligig-fpv, 2016-08-06:
The problem is on a Banggood unit. Let me know if this is an inappropriate place to post.

I need some advice on troubleshooting a noisy OSD Menu screen after power on or switching from video to menu. It is an intermittent problem. The menu picture will clear up after a minute or so. Sometimes it switches just fine without noise. The noise appears as a scrambled picture of the menu with the menu showing up clear for a moment or so. Eventually it all clears up. It's annoying because of the wait. Thanks.

whirligig-fpv, 2016-08-20:
I'm closing this issue. After examining the goggles and board, the layout is a little different from the custom board. It has it's own voltage 5v regulator but the components are the same. Banggood is addressing my issue right now. Whether I get anywhere is another question. Here's a video I sent to them concerning the issue, https://www.youtube.com/watch?v=0m_apSBXDok. In the mean time, I'll think I'll order up a few custom boards and parts from Mouser and bake a couple of these in my reflow oven. Ciao...

Closed 2016-08-20.

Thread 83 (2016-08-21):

Add the ne L-Band (5362 MHz to 5621 MHz)

ps915, 2016-08-21:
Is it possible to add the new L-Band to use this new 48CH [VTx](http://www.banggood.com/FT48X-5_8G-48CH-25200600mW-Adjustable-Video-Transmitter-FPV-Racer-VTX-Raceband-p-1073899.html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)

The new Band has the following channels:
5362 MHz 5399 MHz 5436 MHz 5473 MHz 5510 MHz 5547 MHz 5584 MHz 5621 MHz

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

Would be awesome, because then we have 16 raceband channels which are 37Mhz away from each other

asficas, 2016-09-02:
Done, enjoy!

ps915, 2016-09-03:
Great thanks so much, but you missed the "," buddy =)

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

What about the band Scanner and Auto Seek? Is it a full implementation?
Just flashed it and it seems working =)

asficas, 2016-09-03:
Ohh.. 3 times in fact! Made the corrections just now.
Yes it is a full implementation.
Thank you for starting this great project, I flew my quad yesterday on 5362!
Cheers.

Sent from my Android mobile running Linux.

-------- Original message --------
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

ps915, 2016-09-04:
Thanks =) Well done!

sheaivey, 2016-09-10:
This has been merged into master.

vadimus-ca, 2016-12-08:
Looks like the frequencies used for L band don't match the real products...

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

http://www.banggood.com/Eachine-TX03-Super-Mini-025mW50mW200mW-Switchable-AIO-5_8G-72CH-VTX-600TVL-13-Cmos-FPV-Camera-p-1104884.html

mdmbc, 2016-12-08:
This is probably going to keep happening as long as we keep relying on the non-standard band names vs frequency.

vadimus-ca, 2016-12-08:
True, yet already 2 products have L band listed there.

And 48ch VTX product page used as reference for L band now in code actually does not really claim it is L band.

Is there any online calc so I can encode needed SPI values for those missing bands U,O,L,H?

vadimus-ca, 2016-12-08:
Never mind, used sheaivey's function to calculate needed hex values for L and U bands, will try to test it once my 72ch VTX is delivered.

Someone might ask why do we care about those extra channels? The idea is to spread as much channels over the spectrum as far as you can so you can have a bigger number of pilots flying/racing same time.
Raceband has 8ch spaced by 37MHz and it was the best approach so far but with L and U combined we have 16ch spaced by 40MHz.
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

vadimus-ca, 2016-12-09:
Tested these SPI values with 72ch VTX on L band.

All channels are fine.
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

tipouic, 2016-12-09:
HI @vadimus-ca,I'm very interested for your work because I have the same camera. Can you publish your code and the calculation file in order to add the rest of the frequencies?

vadimus-ca, 2016-12-09:
Sure, here it is: https://docs.google.com/spreadsheets/d/13k_F92v-d6mQLr359WKGDGbnlNQcZMJ6ZbLwvM2zsWU/edit?usp=sharing
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

vadimus-ca, 2016-12-09:
`/*
 * SPI driver based on fs_skyrf_58g-main.c Written by Simon Chambers
 * TVOUT by Myles Metzel
 * Scanner by Johan Hermen
 * Inital 2 Button version by Peter (pete1990)
 * Refactored and GUI reworked by Marko Hoepken
 * Universal version my Marko Hoepken
 * Diversity Receiver Mode and GUI improvements by Shea Ivey
 * OLED Version by Shea Ivey
 * Seperating display concerns by Shea Ivey
 * 10 Favorite channels and functionality by George Chatzisavvidis
 * change in displays by George Chatzisavvidis
 * Adding Fatshark button to work with the module by George Chatzisavvidis

 * The MIT License (MIT)

Copyright (c) 2015 Marko Hoepken

Permission is hereby granted, free of charge, to any person obtaining a copy
of this software and associated documentation files (the "Software"), to deal
in the Software without restriction, including without limitation the rights
to use, copy, modify, merge, publish, distribute, sublicense, and/or sell
copies of the Software, and to permit persons to whom the Software is
furnished to do so, subject to the following conditions:

The above copyright notice and this permission notice shall be included in all
copies or substantial portions of the Software.

THE SOFTWARE IS PROVIDED "AS IS", WITHOUT WARRANTY OF ANY KIND, EXPRESS OR
IMPLIED, INCLUDING BUT NOT LIMITED TO THE WARRANTIES OF MERCHANTABILITY,
FITNESS FOR A PARTICULAR PURPOSE AND NONINFRINGEMENT. IN NO EVENT SHALL THE
AUTHORS OR COPYRIGHT HOLDERS BE LIABLE FOR ANY CLAIM, DAMAGES OR OTHER
LIABILITY, WHETHER IN AN ACTION OF CONTRACT, TORT OR OTHERWISE, ARISING FROM,
OUT OF OR IN CONNECTION WITH THE SOFTWARE OR THE USE OR OTHER DEALINGS IN THE
SOFTWARE.
*/

#include <avr/pgmspace.h>
#include <EEPROM.h>

#include "settings.h"

// uncomment depending on the display you are using.
// this is an issue with the arduino preprocessor

#ifdef OLED_128x64_ADAFRUIT_SCREENS

  #ifdef SH1106
  // #include <Adafruit_SH1106.h>
 #else
    #include <Adafruit_SSD1306.h>
 #endif
    #include <Adafruit_GFX.h>
    #include <Wire.h>
    #include <SPI.h>
#endif
//#ifdef OLED_128x64_U8G_SCREENS
//    #include <U8glib.h>
//#endif
#include "screens.h"
screens drawScreen;

#define EEPROM_ADR_TUNE_FAV_LAST 108

int EEPROM_ADR_TUNE_FAV[10]  = {100, 101, 102, 103, 104, 105, 106,107,110,111};
int temp_EEPROM_ADR_TUNE_FAV[10] = {255, 255, 255, 255, 255, 255, 255,255,255,255};
//setting the 10 favorite channels memory blocks George Chatzisavvidis GC9N

// Channels to sent to the SPI registers
const uint16_t channelTable[] PROGMEM = {
  // Channel 1 - 8
  0x2A05,    0x299B,    0x2991,    0x2987,    0x291D,    0x2913,    0x2909,    0x289F,    // Band A
  0x2903,    0x290C,    0x2916,    0x291F,    0x2989,    0x2992,    0x299C,    0x2A05,    // Band B
  0x2895,    0x288B,    0x2881,    0x2817,    0x2A0F,    0x2A19,    0x2A83,    0x2A8D,    // Band E
  0x2906,    0x2910,    0x291A,    0x2984,    0x298E,    0x2998,    0x2A02,    0x2A0C,    // Band F / Airwave
#ifdef USE_LBAND
  0x281D ,   0x2890 ,   0x2902 ,   0x2915 ,   0x2987 ,   0x299a ,  0x2a0c ,    0x2a1f,    // Band C / Immersion Raceband
//0x2609,    0x261C,    0x268E,    0x2701,    0x2713,    0x2786,    0x2798,    0x280B     // Band D / 5.3
  0x259B,    0x260F,    0x2683,    0x2697,    0x270B,    0x271F,    0x2793,    0x2808     // Band L / 5.3 from 72ch

#else
  0x281D,    0x288F,    0x2902,    0x2914,    0x2987,    0x2999,    0x2A0C,    0x2A1E     // Band C / Immersion Raceband
#endif
};

// Channels with their Mhz Values
const uint16_t channelFreqTable[] PROGMEM = {
  // Channel 1 - 8
  5865, 5845, 5825, 5805, 5785, 5765, 5745, 5725, // Band A
  5733, 5752, 5771, 5790, 5809, 5828, 5847, 5866, // Band B
  5705, 5685, 5665, 5645, 5885, 5905, 5925, 5945, // Band E
  5740, 5760, 5780, 5800, 5820, 5840, 5860, 5880, // Band F / Airwave
#ifdef USE_LBAND
  5658, 5695, 5732, 5769, 5806, 5843, 5880, 5917, // Band C / Immersion Raceband
//  5362, 5399, 5436, 5473, 5510, 5547, 5584, 5621  // Band D / 5.3
  5333, 5373, 5413, 5453, 5493, 5533, 5573, 5621 // proper Band L from 72ch table
#else
  5658, 5695, 5732, 5769, 5806, 5843, 5880, 5917  // Band C / Immersion Raceband
#endif
};

// do coding as simple hex value to save memory.
const uint8_t channelNames[] PROGMEM = {
  0xA1, 0xA2, 0xA3, 0xA4, 0xA5, 0xA6, 0xA7, 0xA8, // Band A
  0xB1, 0xB2, 0xB3, 0xB4, 0xB5, 0xB6, 0xB7, 0xB8, // Band B
  0xE1, 0xE2, 0xE3, 0xE4, 0xE5, 0xE6, 0xE7, 0xE8, // Band E
  0xF1, 0xF2, 0xF3, 0xF4, 0xF5, 0xF6, 0xF7, 0xF8, // Band F / Airwave
#ifdef USE_LBAND
  0xC1, 0xC2, 0xC3, 0xC4, 0xC5, 0xC6, 0xC7, 0xC8, // Band C / Immersion Raceband
  0xD1, 0xD2, 0xD3, 0xD4, 0xD5, 0xD6, 0xD7, 0xD8  // BAND D / 5.3
#else
  0xC1, 0xC2, 0xC3, 0xC4, 0xC5, 0xC6, 0xC7, 0xC8  // Band C / Immersion Raceband
#endif
};

// All Channels of the above List ordered by Mhz
const uint8_t channelList[] PROGMEM = {
#ifdef USE_LBAND
  40, 41, 42, 43, 44, 45, 46, 47, 19, 18, 32, 17, 33, 16, 7, 34, 8, 24, 6, 9, 25, 5, 35, 10, 26, 4, 11, 27, 3, 36, 12, 28, 2, 13, 29, 37, 1, 14, 30, 0, 15, 31, 38, 20, 21, 39, 22, 23
#else
  19, 18, 32, 17, 33, 16, 7, 34, 8, 24, 6, 9, 25, 5, 35, 10, 26, 4, 11, 27, 3, 36, 12, 28, 2, 13, 29, 37, 1, 14, 30, 0, 15, 31, 38, 20, 21, 39, 22, 23
#endif
};

char channel = 0;
uint8_t channelIndex = 0;
uint8_t rssi = 0;
uint8_t rssi_scaled = 0;
uint8_t active_receiver = useReceiverA;
#ifdef USE_DIVERSITY
    uint8_t diversity_mode = useReceiverAuto;
    char diversity_check_count = 0; // used to decide when to change antennas.
#endif
uint8_t rssi_seek_threshold = RSSI_SEEK_TRESHOLD;
uint8_t hight = 0;
uint8_t state = START_STATE;
uint8_t state_last_used=START_STATE;
uint8_t last_state= START_STATE+1; // force screen draw
uint8_t writePos = 0;
uint8_t switch_count = 0;
uint8_t man_channel = 0;
uint8_t last_channel_index = 0;
uint8_t force_seek=0;
uint8_t seek_direction=1;
unsigned long time_of_tune = 0;        // will store last time when tuner was changed
unsigned long time_screen_saver = 0;
unsigned long time_next_payload = 0;
uint8_t last_active_channel=0;
uint8_t seek_found=0;
uint8_t last_dip_channel=255;
uint8_t last_dip_band=255;
uint8_t scan_start=0;
uint8_t first_tune=1;
boolean force_menu_redraw=0;
uint16_t rssi_best=0; // used for band scaner
uint16_t rssi_min_a=RSSI_MIN_VAL;
uint16_t rssi_max_a=RSSI_MAX_VAL;
uint16_t rssi_setup_min_a=RSSI_MIN_VAL;
uint16_t rssi_setup_max_a=RSSI_MAX_VAL;
#ifdef USE_DIVERSITY
    uint16_t rssi_min_b=RSSI_MIN_VAL;
    uint16_t rssi_max_b=RSSI_MAX_VAL;
    uint16_t rssi_setup_min_b=RSSI_MIN_VAL;
    uint16_t rssi_setup_max_b=RSSI_MAX_VAL;
#endif
uint8_t rssi_setup_run=0;

char call_sign[10];
bool settings_beeps = true;
bool settings_orderby_channel = true;
bool HaveFav = false;
bool RefreshFav = false;
uint8_t FirstFav =0;
//bool FATSHARK_BUTTON_PUSHED=false;
//int  LAST_FATSHARK_BUTTON_STATE=0;
int lfavs=0;
// SETUP ----------------------------------------------------------------------------
void setup()
{

  #ifdef Debug
  //Serial.begin(9600);
  #endif

    //
    // IO INIT
    // initialize digital pin 13 LED as an output.
    pinMode(led, OUTPUT); // status pin for TV mode errors
    digitalWrite(led, HIGH);
    // buzzer
    pinMode(CH3, INPUT_PULLUP);//BUTTON FROM FATSHARK
    pinMode(buzzer, OUTPUT); // Feedback buzzer (active buzzer, not passive piezo)
    digitalWrite(buzzer, HIGH);
    // minimum control pins
    pinMode(buttonUp, INPUT);
    digitalWrite(buttonUp, INPUT_PULLUP);
    pinMode(buttonMode, INPUT);
    digitalWrite(buttonMode, INPUT_PULLUP);
    // optional control
    pinMode(buttonDown, INPUT);
    digitalWrite(buttonDown, INPUT_PULLUP);
    pinMode(buttonSave, INPUT);
    digitalWrite(buttonSave, INPUT_PULLUP);
    //Receiver Setup
    pinMode(receiverA_led,OUTPUT);
#ifdef USE_DIVERSITY
    pinMode(receiverB_led,OUTPUT);
#endif
    setReceiver(useReceiverA);
    // SPI pins for RX control
    pinMode (slaveSelectPin, OUTPUT);
    pinMode (spiDataPin, OUTPUT);
    pinMode (spiClockPin, OUTPUT);

    // use values only of EEprom is not 255 = unsaved
    uint8_t eeprom_check = EEPROM.read(EEPROM_ADR_STATE);
    if(eeprom_check == 255) // unused
    {
        // save 8 bit
        EEPROM.write(EEPROM_ADR_STATE,START_STATE);
        EEPROM.write(EEPROM_ADR_TUNE,CHANNEL_MIN_INDEX);
        EEPROM.write(EEPROM_ADR_BEEP,settings_beeps);
        EEPROM.write(EEPROM_ADR_ORDERBY,settings_orderby_channel);
        // save 16 bit
        EEPROM.write(EEPROM_ADR_RSSI_MIN_A_L,lowByte(RSSI_MIN_VAL));
        EEPROM.write(EEPROM_ADR_RSSI_MIN_A_H,highByte(RSSI_MIN_VAL));
        // save 16 bit
        EEPROM.write(EEPROM_ADR_RSSI_MAX_A_L,lowByte(RSSI_MAX_VAL));
        EEPROM.write(EEPROM_ADR_RSSI_MAX_A_H,highByte(RSSI_MAX_VAL));

        // save default call sign
        strcpy(call_sign, CALL_SIGN); // load callsign
        for(uint8_t i = 0;i<sizeof(call_sign);i++) {
            EEPROM.write(EEPROM_ADR_CALLSIGN+i,call_sign[i]);
        }
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

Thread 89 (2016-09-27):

Can't compile for TVout

neirbomit, 2016-09-27:
Hi,
this is the first time posting an issue so hopefully I explain myself in a way that works for everyone.
I've been trying to compile rx5808-pro-diversity for TVout for a couple of days on and off now and have had no success. I got the OLED version compiling (although I don't have a screen so I can't test it). I get warnings about use of memory but other than that all good.  As for the TV out I have included the appropriate libraries (I think) but I get these

Error: unknown opcode `svprt'

for all of the macros in the asm_macros.h file (in TVout/spec). If I try to add #include "spec\asm_macros.h" I just get

Error: Macro `svprt' was already defined

I had been installing a bunch of other GCC libraries for other IDE's and I figured it was possible something got pointed to the wrong library so I ulgraded my arduino from 1.6.11 to 1.6.12 and still ended up with the same errors.  I'm at a loss. Does anybody have any ideas?

Here is a complete listing of the errors I am getting. I can include the verbose version if someone thinks that would be usefull.

Thanks:)

Arduino: 1.6.12 (Windows 7), Board: "Arduino Nano, ATmega328"

C:\Users\Tim\AppData\Local\Temp\ccGSXta1.s: Assembler messages:

C:\Users\Tim\AppData\Local\Temp\ccGSXta1.s:555: Error: unknown opcode `delay2'

C:\Users\Tim\AppData\Local\Temp\ccGSXta1.s:594: Error: unknown opcode `delay1'

C:\Users\Tim\AppData\Local\Temp\ccGSXta1.s:596: Error: unknown opcode `delay2'

C:\Users\Tim\AppData\Local\Temp\ccGSXta1.s:599: Error: unknown opcode `delay2'

C:\Users\Tim\AppData\Local\Temp\ccGSXta1.s:602: Error: unknown opcode `delay2'

C:\Users\Tim\AppData\Local\Temp\ccGSXta1.s:605: Error: unknown opcode `delay2'

C:\Users\Tim\AppData\Local\Temp\ccGSXta1.s:608: Error: unknown opcode `delay2'

C:\Users\Tim\AppData\Local\Temp\ccGSXta1.s:611: Error: unknown opcode `delay1'

C:\Users\Tim\AppData\Local\Temp\ccGSXta1.s:616: Error: unknown opcode `delay1'

C:\Users\Tim\AppData\Local\Temp\ccGSXta1.s:619: Error: unknown opcode `delay3'

C:\Users\Tim\AppData\Local\Temp\ccGSXta1.s:652: Error: unknown opcode `svprt'

C:\Users\Tim\AppData\Local\Temp\ccGSXta1.s:656: Error: unknown opcode `o1bs'

C:\Users\Tim\AppData\Local\Temp\ccGSXta1.s:660: Error: unknown opcode `o1bs'

C:\Users\Tim\AppData\Local\Temp\ccGSXta1.s:661: Error: unknown opcode `delay2'

C:\Users\Tim\AppData\Local\Temp\ccGSXta1.s:663: Error: unknown opcode `o1bs'

C:\Users\Tim\AppData\Local\Temp\ccGSXta1.s:664: Error: unknown opcode `delay2'

C:\Users\Tim\AppData\Local\Temp\ccGSXta1.s:666: Error: unknown opcode `o1bs'

C:\Users\Tim\AppData\Local\Temp\ccGSXta1.s:667: Error: unknown opcode `delay2'

C:\Users\Tim\AppData\Local\Temp\ccGSXta1.s:669: Error: unknown opcode `o1bs'

C:\Users\Tim\AppData\Local\Temp\ccGSXta1.s:670: Error: unknown opcode `delay2'

C:\Users\Tim\AppData\Local\Temp\ccGSXta1.s:672: Error: unknown opcode `o1bs'

C:\Users\Tim\AppData\Local\Temp\ccGSXta1.s:673: Error: unknown opcode `delay2'

C:\Users\Tim\AppData\Local\Temp\ccGSXta1.s:675: Error: unknown opcode `o1bs'

C:\Users\Tim\AppData\Local\Temp\ccGSXta1.s:676: Error: unknown opcode `delay1'

C:\Users\Tim\AppData\Local\Temp\ccGSXta1.s:679: Error: unknown opcode `o1bs'

C:\Users\Tim\AppData\Local\Temp\ccGSXta1.s:681: Error: unknown opcode `delay1'

C:\Users\Tim\AppData\Local\Temp\ccGSXta1.s:683: Error: unknown opcode `o1bs'

C:\Users\Tim\AppData\Local\Temp\ccGSXta1.s:684: Error: unknown opcode `svprt'

C:\Users\Tim\AppData\Local\Temp\ccGSXta1.s:686: Error: unknown opcode `o1bs'

C:\Users\Tim\AppData\Local\Temp\ccGSXta1.s:718: Error: unknown opcode `svprt'

C:\Users\Tim\AppData\Local\Temp\ccGSXta1.s:722: Error: unknown opcode `o1bs'

C:\Users\Tim\AppData\Local\Temp\ccGSXta1.s:725: Error: unknown opcode `delay1'

C:\Users\Tim\AppData\Local\Temp\ccGSXta1.s:727: Error: unknown opcode `o1bs'

C:\Users\Tim\AppData\Local\Temp\ccGSXta1.s:728: Error: unknown opcode `delay3'

C:\Users\Tim\AppData\Local\Temp\ccGSXta1.s:730: Error: unknown opcode `o1bs'

C:\Users\Tim\AppData\Local\Temp\ccGSXta1.s:731: Error: unknown opcode `delay3'

C:\Users\Tim\AppData\Local\Temp\ccGSXta1.s:733: Error: unknown opcode `o1bs'

C:\Users\Tim\AppData\Local\Temp\ccGSXta1.s:734: Error: unknown opcode `delay3'

C:\Users\Tim\AppData\Local\Temp\ccGSXta1.s:736: Error: unknown opcode `o1bs'

C:\Users\Tim\AppData\Local\Temp\ccGSXta1.s:737: Error: unknown opcode `delay3'

C:\Users\Tim\AppData\Local\Temp\ccGSXta1.s:739: Error: unknown opcode `o1bs'

C:\Users\Tim\AppData\Local\Temp\ccGSXta1.s:740: Error: unknown opcode `delay3'

C:\Users\Tim\AppData\Local\Temp\ccGSXta1.s:742: Error: unknown opcode `o1bs'

C:\Users\Tim\AppData\Local\Temp\ccGSXta1.s:743: Error: unknown opcode `delay3'

C:\Users\Tim\AppData\Local\Temp\ccGSXta1.s:745: Error: unknown opcode `o1bs'

C:\Users\Tim\AppData\Local\Temp\ccGSXta1.s:748: Error: unknown opcode `delay2'

C:\Users\Tim\AppData\Local\Temp\ccGSXta1.s:750: Error: unknown opcode `o1bs'

C:\Users\Tim\AppData\Local\Temp\ccGSXta1.s:751: Error: unknown opcode `svprt'

C:\Users\Tim\AppData\Local\Temp\ccGSXta1.s:753: Error: unknown opcode `o1bs'

lto-wrapper: C:\Program Files (x86)\Arduino\hardware\tools\avr/bin/avr-gcc returned 1 exit status

c:/program files (x86)/arduino/hardware/tools/avr/bin/../lib/gcc/avr/4.9.2/../../../../avr/bin/ld.exe: lto-wrapper failed

collect2.exe: error: ld returned 1 exit status

exit status 1
Error compiling for board Arduino Nano.

This report would have more information with
"Show verbose output during compilation"
option enabled in File -> Preferences.

ps915, 2016-09-27:
I was also not able to compile it on tte latest Arduino IDE.

For me the Version 1.6.8 is working without Errors

http://blog.seidel-philipp.de/rx5808-diversity-modul-flashen-laforge-true-d-realacc/#Software

neirbomit, 2016-09-28:
Thank you, that seemed to work (in that it compiles now, I have yet to test functionality or burn it to a board). I'm wondering if the problem is a bug in the new arduino code or just incompatibility or if there is something wrong with my system configuration. It's strange though that the TVout demo projects compiled just fine for me.  Hopefully I won't have any more issues.

sheaivey, 2016-10-10:
This appears to be a non issue.

neirbomit, 2016-10-10:
Only as long as you use Arduino 1.6.8. Later versions do not compile.

akua73, 2016-10-14:
Hello!
Please... pls..Any solution to this erratic behaviour ? I can compile samples of tvout in 1.6.12 but sometimes my own code does not compile showing the same opcodes messages :(
Thks!!!!

neirbomit, 2016-10-14:
Hey akua73,
I was able to compile TVout too but not the rx5808 code I don't know where the problem is but try using version 1.6.8 as that totally fixed the problem with me.  I'm assuming it messes up something when certain combinations of libraries mess up the compiler or linker with some change they've made in Arduino. I don't know how or why but hopefully version 1.6.8 fixes your code too.  It really sucks to be stuck using an old version but maybe they'll fix it at some point.

akua73, 2016-10-14:
thanks a lot for your answer neirbomit,
yes, my code using tv-out library (this one : https://github.com/Avamander/arduino-tvout ) in a pro-micro 5v/16mhz and UI 1.6.8 compiles well, but the result in my tv screen is not stable, the image is erratic ... also the examples in PAL or NTSC : the image in the TV screen is not stable ... :(
so I have two options :
1- try to solve the opcode errors in UI 1.16.12
2- try to solve the unstable tv-out screen using UI 1.16.8
and , if possible , it seems better the option1 :)
don’t know,, i will try to contact arduino developers... and will see...
any other ideas will be very appreciated !
thanks!!
PS: on the other hand,, in tv-out the file video_gen.cpp seems to have all the assembler code that could be causing these errors when compiling, I will take a look here …

Mickyleitor, 2016-10-14:
Hi,
Same happens here in 1.6.12. The same opcode show up using the TV-out library. It's weird as the sample code compile, and as soon as I put more code (even not "playing" with the TV) then It will through those errors..

neirbomit, 2016-10-14:
akua73 - I wonder if the stability is from the version or some other timing thing in your code? 1.6.8 is perfectly stable for me. Is it a possible hard ware problem, loose connection,  wrong resistor value? Maybe even check your actual monitor input with a different source.

Mickyleitor - I just tried to add a bunch of random code to TV-out in 1.6.12 and it compiled for me. Is there a specific library that you added or specific piece of code that you added when it stopped compiling? Maybe try and compile for a different board?

Mickyleitor, 2016-10-14:
@neirbomit I'm using TVout.h and fontALL.h, I will add more in the future but It's ok for debug purposes. The code is using the standard serial to read and print from/to the keyboard/monitor (I know, this will stop momentany the TV streaming but not really a problem for my application).
I will try to take out different parts of code finding out what code could be.

neirbomit, 2016-10-14:
@akua73, Mickeyleitor just gave me an idea for your stability problem. It might not be the issue but Serial.print statements are blocking in arduino if there is too much data for the buffer.  If you are using a lot of print statements you might want to consider commenting them out to see if this fixes you problem.  If it does you might want to check the buffer flags before writing anything to serial. Or maybe even switching to a much higher serial rate.

akua73, 2016-10-14:
I think i already tested it (remove all serial debug prints)... Dont remember .... On the other hand I can not test anything by now... But  I will try all the ideas in my next experiments session... Thanks for the help

akua73, 2016-10-17:
Now i see that all these problems regarding macros were already discovered in the first post ;) ... Sorry!
Maybe we can just substitute the code in the macros directly in video_gen.cpp .... Dont know...

neirbomit, 2016-10-17:
@akua73 It's really just weird. If you look at the macros that (delay2 for example) that's all it's doing, it should just be replacing the itself with a couple of nops before being compiled. Something in the linker has got to be messed up, but why sometime and not others and why with the newer versions.  I'll have to look over the code again. I'm not sure what #define REMOVE6C etc do. that's a step in the right direction though... maybe.

akua73, 2016-10-17:
well, at the end I achieved , more or less, the goal : it compiles and it works (in 1.6.12)... but yes.. very extrange,,, i dont know why the macros are not running properly ...
the solution was simply to substitue delay1,delay2,delay3, o1bs and svprt code directly ...

I used this sed file if someone is interested in doing the same workaround:

```
s/"delay3\\n\\t"/"nop\\n\\t"\n"nop\\n\\t"\n"nop\\n\\t"/g
s/"delay2\\n\\t"/"nop\\n\\t"\n"nop\\n\\t"/g
s/"delay1\\n\\t"/"nop\\n\\t"/g
s/"svprt\t\%\[port\]\\n\\t"/"in             r16,\%\[port\]\\n\\t"\nANDI_HWS/g
s/"o1bs\t\%\[port\]\\n\\t"/BLD_HWS\n        "out \%\[port\],r16\\n"/g
s/"o1bs\t\%\[port\]\\n"/BLD_HWS\n        "out \%\[port\],r16\\n"/g
```

and this command:

`cat ../video_gen.cpp_BACKUP | sed -f fixit.sed > /root/Arduino/libraries/TVout/video_gen.cpp`

now it works well with an 'stable' image on the monitor
i suposse it will be a bug, but i dont know where...

now next step is how to pause and resume the tv signal ... ;)  will see.
regards.-

BoRKeLSNoRKeL, 2016-12-03:
I have the same error , i''m kind of new in programming .
in one cees the code compiles and for example if i change an print command to println , the code would not compile.
akua73 used a work around , but i dont realy know how to do that. .... just copy paste in video_gen.cpp ?
what is a sed file ?
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

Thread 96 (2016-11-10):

Recovery after failed flash

robert-hoffmann, 2016-11-10:
Sorry this is probably not the right place to ask ..but

I bought the built verion of this, and had a power failure while uploading the hex firmlware file, and now the board will not boot, and i can't seem to reflash it either.

Is there a jumper or method to recover and be able to reflesh the firmware, or am i good to buy another one ?

Thanks for your time !
Robert

kabturek, 2016-11-19:
it would be better to ask on the rcgroups thread but if you cant flash the atmega/arduino you can check:
http://arduino.stackexchange.com/questions/13292/have-i-bricked-my-arduino-uno-problems-with-uploading-to-board
The 'built' version is similar to an arduino (with atmega328). but is programmed with usbasp.

generally its hard to 'brick' an arduino using a usbasp. try to debug if it isnt a another problem (voltage regulator etc)

sheaivey, 2016-12-09:
Questions like this should be asked over in the RCGroups thread for quicker response.

Thanks!

https://www.rcgroups.com/forums/showthread.php?2477752-DIY-Diversity-Receiver-rx5808-pro-diversity/

Closed 2016-12-09.

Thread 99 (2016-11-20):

72 channels

carebear482, 2016-11-20:
I saw a new micro camera with vtx is coming out featuring 72 channels, can this be supported?
link to product: http://tinyurl.com/zaq2s8v

kabturek, 2016-11-20:
its shouldn't be a big problem to support - i could write it but i dont have any transmitter that supports it.

vadimus-ca, 2016-12-08:
The L band already in the code seems to be different from the manual that came with 72ch AIO camera/VTX.

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
Instead of
5362, 5399, 5436, 5473, 5510, 5547, 5584, 5621
it should be
5333, 5373, 5413, 5453, 5493, 5533, 5573, 5613

Is there some calculator available to find out what corrected SPI values to put in channelTable[]?

kabturek, 2016-12-09:
it depends where you check ;-)
https://www.rcgroups.com/forums/showthread.php?2592505-New-L-band-on-5-8Ghz

here are some tips about spi values:
https://github.com/sheaivey/rx5808-pro-diversity/issues/75

vadimus-ca, 2016-12-09:
Actually I already calculated those values, flashed and tested L band transmission, but thanks anyway.

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

sheaivey, 2016-12-09:
Please pay attention to your local laws when messing with these "new bands" as they are not legal in the US. No sane US based company will sell you these VTX as the fines are quite large.

This has been discussed before...
https://github.com/sheaivey/rx5808-pro-diversity/pull/86#issuecomment-246065178

If you are going to implement these new frequencies you need to wrap the changes in a feature toggle before I will approve any PR.

Thanks

vadimus-ca, 2016-12-09:
Sure thing applicable regulations should be followed.

tipouic, 2016-12-21:
If you want the 72 chnanels, you can find the code here [https://github.com/tipouic/rx5808-pro-diversity](url)

tigert, 2017-04-05:
There are weather radars on those channels.

https://www.sciencenews.org/sites/default/files/main/articles/102215_ts_radar_free.jpg < if you start to see stuff like this on weather radar, it's not very hard to predict how nice freedoms we will have in our hobby in the future.

Those channels are illegal, also outside the US and should not be used.

https://www.youtube.com/watch?v=YipWLgu_NjY

sheaivey, 2017-05-05:
Closing this issue as there is another fork supporting those 72 channels.

Closed 2017-05-05.

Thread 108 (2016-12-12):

Add third receiver

error414, 2016-12-12:
Hi,

is it possible add third receiver? I tried it and it seems that its easy to modify current pdb layout to add third receiver. 4066 has one free switch for it. My code is proof of concept but I tried use it on field and it works excelent.

http://petr-cada.cz/repo/rx5808-diversity/commit/8a358963cfd82186f173ed7609000b23455daa0b

https://youtu.be/HE94wPLSXsk

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

sheaivey, 2016-12-13:
Have a look at @rcdesigns MultiDiversity fork... This probably won't get implemented into the main project unless some one wants to head up doing all the documentation and design boards around it.

https://github.com/rcdesigns/rx5808-pro-diversity/tree/MultiDiversity

Closed 2016-12-13.

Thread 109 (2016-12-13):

How to update your firmware

c4talyst, 2016-12-13:
I'd love to help out writing some documentation on 'How-To' guides for users to update their firmware on their devices. If anyone can give me a basic overview on what hardware & software is required I can very happily submit a PR to update the readme :)

Knifa, 2016-12-13:
That sounds super great! It's hard to be specific without knowledge of particular hardware choices, etc, but I guess on a basic level it kind of goes like the following.

- Install the latest Arduino IDE.
- Figure out which hardware you have (OLED? diversity? Nano-based? etc.)
- Update `settings.h` to match your configuration.
- Install libraries that are required for your configuration (Adafruit_GFX, TVOut, etc)
- Use an FTDI adapter (or another Arduino) to connect to the FTDI pins on your device.
- Upload the firmware.

I think maybe some walkthroughs for specific hardware would be good.

vadimus-ca, 2016-12-15:
If USBasp adapter is being used for flashing under Windows 10 libUSB**k** driver should be selected for proper firmware uploading (Sketch - Upload using programmer)

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

c4talyst, 2016-12-29:
Thanks for the tips! Running through the steps now, and have run into a stumbling block. Perhaps just a newbie error?

OS: MacOS Sierra (10.12.2)
Arduino IDE 1.8.0
Installed libraries
* Adafruit SSD1305 by Adafruit (used 1.1.2)
* Adafruit GFX Library by Adafruit (used 1.1.5)
* TVOut by mdmetzie@gmail.com (used 1.0.5)

Is this perhaps something I have neglected to configure in settings.h ?

Error:
```
Arduino: 1.8.0 (Mac OS X), Board: "Arduino Nano, ATmega328"

/Applications/Arduino.app/Contents/Java/arduino-builder -dump-prefs -logger=machine -hardware /Applications/Arduino.app/Contents/Java/hardware -tools /Applications/Arduino.app/Contents/Java/tools-builder -tools /Applications/Arduino.app/Contents/Java/hardware/tools/avr -built-in-libraries /Applications/Arduino.app/Contents/Java/libraries -libraries /Users/dan/Documents/Arduino/libraries -fqbn=arduino:avr:nano:cpu=atmega328 -ide-version=10800 -build-path /var/folders/h0/39cpp_bd0vq42dw980yb47_80000gp/T/arduino_build_965409 -warnings=none -prefs=build.warn_data_percentage=75 -prefs=runtime.tools.avr-gcc.path=/Applications/Arduino.app/Contents/Java/hardware/tools/avr -prefs=runtime.tools.arduinoOTA.path=/Applications/Arduino.app/Contents/Java/hardware/tools/avr -prefs=runtime.tools.avrdude.path=/Applications/Arduino.app/Contents/Java/hardware/tools/avr -verbose /Users/dan/dev/github/sheaivey/rx5808-pro-diversity/src/rx5808-pro-diversity/rx5808-pro-diversity.ino
/Applications/Arduino.app/Contents/Java/arduino-builder -compile -logger=machine -hardware /Applications/Arduino.app/Contents/Java/hardware -tools /Applications/Arduino.app/Contents/Java/tools-builder -tools /Applications/Arduino.app/Contents/Java/hardware/tools/avr -built-in-libraries /Applications/Arduino.app/Contents/Java/libraries -libraries /Users/dan/Documents/Arduino/libraries -fqbn=arduino:avr:nano:cpu=atmega328 -ide-version=10800 -build-path /var/folders/h0/39cpp_bd0vq42dw980yb47_80000gp/T/arduino_build_965409 -warnings=none -prefs=build.warn_data_percentage=75 -prefs=runtime.tools.avr-gcc.path=/Applications/Arduino.app/Contents/Java/hardware/tools/avr -prefs=runtime.tools.arduinoOTA.path=/Applications/Arduino.app/Contents/Java/hardware/tools/avr -prefs=runtime.tools.avrdude.path=/Applications/Arduino.app/Contents/Java/hardware/tools/avr -verbose /Users/dan/dev/github/sheaivey/rx5808-pro-diversity/src/rx5808-pro-diversity/rx5808-pro-diversity.ino
Using board 'nano' from platform in folder: /Applications/Arduino.app/Contents/Java/hardware/arduino/avr
Using core 'arduino' from platform in folder: /Applications/Arduino.app/Contents/Java/hardware/arduino/avr
Build options changed, rebuilding all
Detecting libraries used...
"/Applications/Arduino.app/Contents/Java/hardware/tools/avr/bin/avr-g++" -c -g -Os -w -std=gnu++11 -fpermissive -fno-exceptions -ffunction-sections -fdata-sections -fno-threadsafe-statics  -flto -w -x c++ -E -CC -mmcu=atmega328p -DF_CPU=16000000L -DARDUINO=10800 -DARDUINO_AVR_NANO -DARDUINO_ARCH_AVR   "-I/Applications/Arduino.app/Contents/Java/hardware/arduino/avr/cores/arduino" "-I/Applications/Arduino.app/Contents/Java/hardware/arduino/avr/variants/eightanaloginputs" "/var/folders/h0/39cpp_bd0vq42dw980yb47_80000gp/T/arduino_build_965409/sketch/rx5808-pro-diversity.ino.cpp" -o "/dev/null"
"/Applications/Arduino.app/Contents/Java/hardware/tools/avr/bin/avr-g++" -c -g -Os -w -std=gnu++11 -fpermissive -fno-exceptions -ffunction-sections -fdata-sections -fno-threadsafe-statics  -flto -w -x c++ -E -CC -mmcu=atmega328p -DF_CPU=16000000L -DARDUINO=10800 -DARDUINO_AVR_NANO -DARDUINO_ARCH_AVR   "-I/Applications/Arduino.app/Contents/Java/hardware/arduino/avr/cores/arduino" "-I/Applications/Arduino.app/Contents/Java/hardware/arduino/avr/variants/eightanaloginputs" "-I/Applications/Arduino.app/Contents/Java/hardware/arduino/avr/libraries/EEPROM/src" "/var/folders/h0/39cpp_bd0vq42dw980yb47_80000gp/T/arduino_build_965409/sketch/rx5808-pro-diversity.ino.cpp" -o "/dev/null"
"/Applications/Arduino.app/Contents/Java/hardware/tools/avr/bin/avr-g++" -c -g -Os -w -std=gnu++11 -fpermissive -fno-exceptions -ffunction-sections -fdata-sections -fno-threadsafe-statics  -flto -w -x c++ -E -CC -mmcu=atmega328p -DF_CPU=16000000L -DARDUINO=10800 -DARDUINO_AVR_NANO -DARDUINO_ARCH_AVR   "-I/Applications/Arduino.app/Contents/Java/hardware/arduino/avr/cores/arduino" "-I/Applications/Arduino.app/Contents/Java/hardware/arduino/avr/variants/eightanaloginputs" "-I/Applications/Arduino.app/Contents/Java/hardware/arduino/avr/libraries/EEPROM/src" "-I/Users/dan/Documents/Arduino/libraries/Adafruit_SSD1306" "/var/folders/h0/39cpp_bd0vq42dw980yb47_80000gp/T/arduino_build_965409/sketch/rx5808-pro-diversity.ino.cpp" -o "/dev/null"
"/Applications/Arduino.app/Contents/Java/hardware/tools/avr/bin/avr-g++" -c -g -Os -w -std=gnu++11 -fpermissive -fno-exceptions -ffunction-sections -fdata-sections -fno-threadsafe-statics  -flto -w -x c++ -E -CC -mmcu=atmega328p -DF_CPU=16000000L -DARDUINO=10800 -DARDUINO_AVR_NANO -DARDUINO_ARCH_AVR   "-I/Applications/Arduino.app/Contents/Java/hardware/arduino/avr/cores/arduino" "-I/Applications/Arduino.app/Contents/Java/hardware/arduino/avr/variants/eightanaloginputs" "-I/Applications/Arduino.app/Contents/Java/hardware/arduino/avr/libraries/EEPROM/src" "-I/Users/dan/Documents/Arduino/libraries/Adafruit_SSD1306" "-I/Applications/Arduino.app/Contents/Java/hardware/arduino/avr/libraries/SPI/src" "/var/folders/h0/39cpp_bd0vq42dw980yb47_80000gp/T/arduino_build_965409/sketch/rx5808-pro-diversity.ino.cpp" -o "/dev/null"
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
c4talyst, 2016-12-29:
Excuse me, I read the error message now... Basically:

Adjust Adafruit_SSD1306.h file under the `SSD1306 Displays` heading to look like the following:
```
#define SSD1306_128_64
// #define SSD1306_128_32 // this is uncommented by default
// #define SSD1306_96_16
```

Knifa, 2016-12-29:
Glad you got it sorted! I really dislike this design choice on Adafruit's part. Needing to edit library code is super nasty.

TimothyGold, 2017-05-24:
I was able to build this update for upload but I accidentally loaded the bootloader version and I cannot update in any way now. It is using the loaded version but when I try to upload again it states that  "stk500 get sync fails"  Can someone provide a recommended solution?

Knifa, 2017-05-24:
@TimothyGold: Ouch, that sucks. I ran into the same issue with a friends' module who did the same.

I fixed it using the ISP header and [ArduinoISP](https://www.arduino.cc/en/Tutorial/ArduinoISP). The ArduinoISP might help you out (where the target is your receiver, rather than another Arduino).

What type of receiver do you have?

TimothyGold, 2017-05-24:
I have a Realacc - rx5808-pro-diversity.  Its been a while but I have a USB ASP and i think I can flash on ISP.  Once I flash the non bootloader version will I be able to use XLoader to flash updates via the FTDI interface?  Or does this require a bootloader to flash via the serial interface?

Knifa, 2017-05-24:
If you undo the screws and disconnect the top PCB with the screen, there are ISP headers underneath.

Use your USB ASP and the ISP header to burn the Arduino bootloader. Once you've flashed the bootloader, use the FTDI pins to flash the non-bootloader version. You can continue to use the FTDI header for updates afterwards.

I guess you could also just flash the bootloader version using your USB ASP (then the FTDI will still work afterwards.)

Just, for whatever reason, trying to flash the version with the bootloader over FTDI causes weird problems.

Hope that makes sense!

TimothyGold, 2017-05-24:
This makes sense.  Thank you for your help.

TimothyGold, 2017-05-24:
One more question.  What Arduino Bootloader works best.  I see some people have tried UNO and others something else.  Any recommendations?  Thanks again.

Knifa, 2017-05-24:
Not sure on that, I used whatever it gives you with the Nano device type.

TimothyGold, 2017-05-24:
OK.  That's what I will use.

brkdwn, 2017-05-30:
I have the same issue. On both a Realacc rx 5808 split (12/2016) and a non split version (05/2017). This is where I am so far:

FTDI:
-I can't flash hex files with Xloader, it says: Upload failed
-I can compile, write, but fail to  verify with arduino

USBasp:
-I can compile and flash on ISP ports
-I can burn the bootloader (not sure if I should use nano or mega 328p, I tried both)

After burning the bootloader, I have no change with FTDI, still not possible to flash. I can only flash with xloader or arduino if I flash the same firmware witch is already on it.

So it's look like I can't manage to repair the bootloader correctly, but at least i can still flash threw USBasp. But only if I have an .ino. Is there a way to flash a .hex with USBasp ?

THX for the good work.

TimothyGold, 2017-05-30:
I was able to burn the Nano bootloader via USBasp and the ISP headers.  You can flash the .hex via the USBasp via the ISP headers.  I can now upload via FTDI fine without issue once the bootloader was repaired.  Not sure what you are facing at this point.

brkdwn, 2017-05-30:
Thank for confirming that I should be succesful. I will try further.

Can you tell me how are you flashing hex file with USBasp ?

TimothyGold, 2017-05-30:
Its been a while but I think you can pick the USBasp as the programmer in the Arduino IDE and then program like you normally would via the ISP header.  You will have to do all programming via ISP header.

brkdwn, 2017-05-31:
Ok It was a driver issue, now the bootloader is working again, an i can flash witfh ftdi again

thx

pbootsma, 2017-08-28:
I just want to add that I finally got the hex flashing with USBASP working on MacOS 10.12 Sierra with the following command if Arduino IDE (1.8.4) is installed:

/Applications/Arduino.app/Contents/Java/hardware/tools/avr/bin/avrdude -C/Applications/Arduino.app/Contents/Java/hardware/tools/avr/etc/avrdude.conf -v -patmega328p -cusbasp -Uflash:w:Downloads/rx5808-pro-diversity-v2.0-with-bootloader.hex

You have to omit the -D parameter (Disable auto erase for flash memory), otherwise you get verification errors.

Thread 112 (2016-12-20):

Break out SPI commands into own file

sheaivey, 2016-12-20:
Simplified receiver SPI command function.

Knifa, 2016-12-20:
So I've got this one already in this [commit](https://github.com/sheaivey/rx5808-pro-diversity/pull/106/commits/e96217aee8795f5c45be55dd6c0fc0b555926d64) but I'm keen to move those out further.

sheaivey, 2016-12-21:
If i remember correctly the current code is just bit-banging out the commands and does not even need the SPI library. That said the bit-banging code is very dirty haha.

Knifa, 2016-12-21:
Yep, I was wondering if I could maybe simplify by just using whatever Arduino has already but it turns out bit banging is totally spot on. I tidied it up a bit at least. :)

Knifa, 2016-12-23:
https://github.com/sheaivey/rx5808-pro-diversity/pull/106/commits/1dbce46f2668854827628454ae9300d1de69cf8e

Moved these out a bit more now --- not sure if calling the broken out files "driver" is the best bet since the other file still deals with RSSI reads etc. Bit nicer though!

Knifa, 2017-03-13:
Closing this as I think they've been moved!

Closed 2017-03-13.

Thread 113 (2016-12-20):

Refactor main loop into smaller functions and files so it's easy to follow.

sheaivey, 2016-12-20:

Knifa, 2016-12-20:
Some general unsorted thoughts around this:

- Ideally split up so states are non-blocking (i.e., no do-while loops for locking in a particular state). Means we can still arrange for other stuff to happen easily (like update RSSI values in one place, do diversity switching in one place, etc.)
- Need a way to deal with button presses centrally given the above. I'm thinking maybe heading towards somehow event based? Not sure how the overhead would work out on this on the AVR chips.

I will try head for literally splitting it up as is for now, though.

sheaivey, 2016-12-21:
Those are some good goals and are some of the first things I did when creating the La Forge FPV fork as the main loop was a disaster.

Knifa, 2016-12-23:
Starting to make a go at this now. Keen to hear thoughts on the way I'm doing the state machine.

https://github.com/sheaivey/rx5808-pro-diversity/pull/106/commits/d997e5960d3552a5b208843b3094249bd4bcb920

I wanted to avoid using huge switch statements where possible but I'm aware of the potential issues with memory usage. Still trying to work it out as I'm going along!

Knifa, 2016-12-23:
https://github.com/sheaivey/rx5808-pro-diversity/pull/106/files#diff-dc7eb18d61c1335e0c1a37dba8755681 good example here too, maybe?

Knifa, 2016-12-23:
Making good progress on this. Manual, seek, bandscanner and screensaver all working! It's made it so much faster to get stuff working at the very least.

Knifa, 2017-03-13:
:+1:

Closed 2017-03-13.

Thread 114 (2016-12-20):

Refactor GUI and menu logic.

Knifa, 2016-12-20:
This is what got me started in the first place since I found it so hard to make new menus! Looking to  refactor GUI code and menu logic such that new menus can be added and modified easily, along with generally tidying stuff up.

General ideas:
- Make a mini-toolkit for making menus of arbitrary length, function and control (e.g., support character field or numerical values elsewhere).
- Possibly use hooks for the above so you can attach functions to particular menu items (rather than detecting specific menu IDs and doing stuff based on that in one big function)
- Make it easy to deal with overall. Dealing with this stuff manually is super boring so let's make it easy for other devs to customize stuff and add new features.
- (Possibly a big one, for another issue perhaps) Generalise enough that OLED and TVOUT can share the same/similiar code.

I have a bit of an issue here where my device doesn't have TVOUT by default so I might need to bodge it a little bit so I can test and refactor this too.

sheaivey, 2016-12-21:
Breaking down the views into basic components will help tremendously and help standardize the basic look and feel. If you can make these components responsive based off screen width/height you will have a big step towards being able to reuse the screens for different screen resolutions (TVOUT/OLED).

You will also run into the fact that the TVOUT library does not follow the same graphics style as the Adafruit graphics library. Honestly it would be easier to re-create the TVOUT library to extend the Adafruit graphics library like the OLED library does. All that would need to be created would function how a pixel gets drawn onto the TV screen and Adafruit handles the draw functions and screen buffer. (This would require some more in-depth knowledge on how to generate NTSC/PAL signals)

Then you just swap which library is being used in the settings.h

Those are just some more ideas I had to help bridge the gap between OLED/TVOUT but by no means something you have to take on.

-Shea

sheaivey, 2017-05-15:
This has been accomplished with the release of v2.0

balrog-kun, 2017-06-08:
To be clear, the part about TVout support isn't done, right?  As far as I can tell there's no support code anymore.

Is anyone working on re-adding that?

Closed 2017-05-15.

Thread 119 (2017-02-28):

Support for RX5809

paulelsner, 2017-02-28:
Hi,
is it possible to support this module: http://www.banggood.com/Realacc-RX5809-5_8G-48CH-Diversity-FPV-Receiver-SMA-90-120-Degree-Adapter-For-Fatshark-Goggles-p-1127467.html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

so that features like a band scanner will be available?

Knifa, 2017-03-05:
I feel like this is probably just the RX5808 module with the name wrong. If you can crack the shielding open and enable SPI you might be able to control it with an Arduino (and then everything would work).

No microcontroller on there though so you'd need to hack it together.

Give it a go!

Closed 2017-03-05.

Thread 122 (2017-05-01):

Audio

witorwitor, 2017-05-01:
Great project! I would like to put rx pro diversity in the cheap Eachine VR-007 Pro. Is there a way to get audio as well as video? I don't see anything related to audio signal on the schematics.

Knifa, 2017-05-04:
Going to close this since we answered in the Gitter. :smile:

For anyone looking in future, the audio out can be connected to the 4066 switch and switched along with the video.

Closed 2017-05-04.

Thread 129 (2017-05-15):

Update while module installed

19Gerhard85, 2017-05-15:
Hey guys,

I have quick question: Is it ok, to update the module while it's installed in the goggles (not powerd up)?

Greets

Knifa, 2017-05-15:
It depends on your particular module but I would recommend taking it out. The RealAcc version tries to backpower the goggles through the 5V rail (without success!).

19Gerhard85, 2017-05-15:
I'm using the Realacc module. Can the backpower damage the googles?

Knifa, 2017-05-15:
It could make the voltage regulator a little upset, but not sure about real damage. The main problem is that (assuming it's powered over USB) your power source might go overcurrent.

Still strongly advise just taking it out!

19Gerhard85, 2017-05-15:
Ok. Thank you very much!

Closed 2017-05-15.

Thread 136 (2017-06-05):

No video output

teozfrank, 2017-06-05:
Hi,

I am using the RX5808-pro-basic and I cannot get video to display, I have it wired as shown and have the sketch on my arduino mini. I am using a PAL monitor, could you offer any advice?

Kind Regards,
Frank

sheaivey, 2017-06-05:
You will need to use Release v1.2 for video instead if you are not using the OLED display.

https://github.com/sheaivey/rx5808-pro-diversity/releases/tag/v1.2

teozfrank, 2017-06-05:
Ah perfect thank you!

Only problem is, I get a blank screen now instead of no signal, any ideas?

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

teozfrank, 2017-06-05:
Ok I got it, just needed to press a button, awesome thank you!

Closed 2017-06-05.

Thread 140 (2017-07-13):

TVout,Can't compile

Armagedon13, 2017-07-13:
hi i can't compile, and yes, i read the closed issue, but, i don't have linux for remplace the archive. Can someone pass me the cpp file?

stray77, 2017-07-19:
Does this help?  I really can't tell what you're looking for.
https://github.com/Avamander/arduino-tvout

caveymon, 2017-08-16:
I had this issue too. Some compiler switches have changed between arduino ide versions, and newer (1.8+) don't seem to support macros anymore.

I patched the tvout library included in this project on my own local copy. Haven't bothered to push the changes, maybe I should somehow.

havent been able to test it yet, but I needed it for a small modification I did to the schematics. Not sure if it has the sorted effect though :)

GregTronics, 2017-10-03:
Per the closed thread, the way to fix this error is to go into the video_gen.cpp file and replace all the asm macros with the asm functions.  My patched one is attached.  Works with newest compiler and can confirm the screen works again.
[video_gen.zip](https://github.com/sheaivey/rx5808-pro-diversity/files/1351145/video_gen.zip)

johnbentcope, 2018-04-14:
GregTronics, replacing video_gen.cpp in the library folder results in new errors, mostly stating "Error: macro 'macroNameHere' was already defined. Any thoughts?

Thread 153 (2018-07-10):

How are the RSSI Values created?

swatza, 2018-07-10:
I was trying to dig through the code as I am using this as a low cost sensor for some RF research to figure out what the outputted value represents. The best guess I have is that its an RCPI 8bit between 0-220 (as comments I found indicated min values were 90 and max were 220) but I am not sure if that mapping is correct.

Any information about the exact details would be helpful.

JyeSmith, 2018-07-10:
In receiver.cpp you can see the analogRead function which reads the RSSI value.

The below link explains the returned value 😃

https://www.arduino.cc/en/Tutorial/AnalogInput

swatza, 2018-07-10:
Okay, so if I am understanding this correctly: mapping 0-1023 from 90 to 220 or 0 to 100. Therefore 90 would equal 0 Volts and 220 should equal 5V or 100%.

JyeSmith, 2018-07-11:
The RSSI min/max output range isn't from 0 to 5v, but more like 0.5 to 1.2.  Hence the min and max calibration values are only ~90 to ~220.

The 0 to 100 conversion you see in the code is to normalise Rx modules on the same scale. It then makes it easy to see a 2% difference, which is the threshold for switching between the Rx modules.

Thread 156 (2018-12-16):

SPI OLED Screen?

akosfonod, 2018-12-16:
I have ordered by mistake an SPI version of an OLED screen (SSD1306), beside the fact that the module itself can be re-configured with some additional small SMD resistors,but it was pretty easy to surround the display constructor with some defines and call the appropriate SPI version constructor of the adafruit driver lib. I have already tested the SPI version it works flawlessly.
Is anyone intrested? Is this project still alive?

JyeSmith, 2018-12-17:
SPI should be much faster than I2C, particularly when its not bit banged.  So it would be useful to speed up the loop.  But everyone has moved onto STM32F1 which is much faster.

With that said its pretty dead in here :(

Personally I dont see the need for the OLED and have removed it from my VRx.

akosfonod, 2018-12-17:
The way how I have modified it is using the HW SPI, so no bitbanging.
@JyeSmith Can you pls name the  STMF1 repo?
Thank you :)
I will close the the Issue afterwards.

JyeSmith, 2018-12-17:
piodabro/WPro58 has an active community. They concentrate on the Eachine module and adding OSD functionality.

JyeSmith/FENIX-rx5808-pro-diversity is my fork.  The recent master is for quadversity, but at the moment Im concentrating on using a touchpad and improving in goggle menu functionality (check the touch (STM32F1 based) and esp32 (**this is more active**) branches).  Hence the comment about the OLED being redundant.

There are a couple more which havent been active in over a year.

Closed 2018-12-17.

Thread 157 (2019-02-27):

Button is not a class or namespace

Ediher0504, 2019-02-27:
I got an error Button is not a class namespace When compiling

JyeSmith, 2019-02-28:
What version IDE are you using?  Master complied correctly for me on 1.8.8.

Ediher0504, 2019-02-28:
I use IDE 1.6, well, I will try the version you recommend, thank you for your response

Ediher0504, 2019-03-01:
Last problem,  error compiling for board arduino nano

JyeSmith, 2019-03-01:
Can you take a screen shot of your board settings in the Arduino IDE and post your error message.

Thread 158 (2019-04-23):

help wanted: how can it be changed to communicate with another module in quadversity?

laurentopia, 2019-04-23:
I'm thinking ev200d here, their modules are based on this project it seems. They suck so I'm wondering if this can be changed in firmware so both modules communicate and decide which has the best RSSI and switch globally to it (in the ev200d).
Any help appreciated.

JyeSmith, 2019-04-23:
https://github.com/JyeSmith/FENIX-rx5808-pro-diversity/tree/quadversity

This is a fork I developed a little back adding quadversity to the rx5808-pro-diversity.  I have no idea how the EV200 is set up to do it, but if you spend some time with a multimeter poking around you could figure it out and report back :D

laurentopia, 2019-04-23:
Thank @JyeSmith.
I've never done that sort of poking but the goggles are open so it's a good chance to do it, what do you recommend I start with to see what's needed?

JyeSmith, 2019-04-23:
It mightn't be so easy if you've never done it before and no familiar with module schematics.  But at a minimum find out what the module-to-goggle sockets connect to.

laurentopia, 2019-04-24:
Do you have a pinout of a standard fatshark module?

JyeSmith, 2019-04-24:
Check the readme for the connections.

laurentopia, 2019-04-24:
The readme contains only the connections of each components, not the pinout to the goggles

JyeSmith, 2019-04-24:
https://www.rcgroups.com/forums/showatt.php?attachmentid=11192179

laurentopia, 2019-04-25:
Thanks!
Did you build your project with 4 rc5808 inside one module?
I see that it could be turned into 2 diversity modules that connects like that image, (is it the source of Lagorge?)
Since many people are getting rid of their default ev200d module (some batches loose lock mid air) I'm thinking that would be a great alternative.

JyeSmith, 2019-04-26:
I did build an Arduino based quadversity Rx and a STM32 based module for Fatsharks.

https://imgur.com/a/yCRRbOW

laurentopia, 2019-04-26:
Quite a contraption, which one am I looking at and how does it "fly" ?

JyeSmith, 2019-04-27:
This is a prototype STM32 module. Works just like a diversity with more patch antennas :)

laurentopia, 2019-04-28:
nice long coverage :) how fast is commutation?

JyeSmith, 2019-04-29:
Current switching rate is about 15kHz in 2 antenna diversity mode.

laurentopia, 2019-05-02:
So do you stitch the image per line?
I thought Xversity was commutating at the end of the last scanline.

brainbubblersbest, 2020-02-22:
Hello, figured out that the stock modules are communicating over SPI at the first Three FS module Contacts.
The Resistors on the 5808 Modules are not existent. (removed the shielding)
And the Ch1, Ch2, Ch3, Contacts from each RX are connected to the three first contacts Button 1,2,3 in module bay. With 0,1ohms!

Also the RSSI is not output to the pin 8 of FS Bay.
Seems Signal Quality will only reported over SPI?

I figured out that RSSI is connected to this tiny Board upside from each RX5808 Boards.
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

Can Provide measurement with scopemeter. Have two Pro58 Boards.
Maybe some Hardware modification is needed to allow communication for STM32 to the Google.

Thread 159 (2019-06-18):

Open pilot branded rx5808 pro diversity

stevefoxuk, 2019-06-18:
Ive tried to find info on this but cannot find anything definitive.

Can this firmware be flashed to the openpilot branded rx5808 pro diversity module?
this is the exact unit im talking about:  https://www.aliexpress.com/item/32703859969.html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

Thanks in advance, steve.

JyeSmith, 2019-06-18:
I would be very suprise if it couldn't.

stevefoxuk, 2019-06-30:
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

This is the board i would like to know if i can flash this firmware too, i have examined the board against Shea Ivey designed boards and they are 'almost' identical play the component values are the same as are the two IC's on the board but i want to make sure and not risk bricking the board!

mozgoverflow, 2019-10-23:
Hi,
I have similar module.

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

Flashed with latest release (built from sources in Arduino IDE 1.8.9) and flashed via USBasp programmer.

At first look, it works, but I have strange bug on OLED: image is interlaced and stretched vertically 2x.

What things I could try to fix this?

mozgoverflow, 2019-10-23:
Update:

I have flashed prebuilt HEX (from Releases) and now it works without OLED issues.

stevefoxuk, 2019-10-23:
We both have the exact same unit, mine only looks slightly different because I have removed the oled and soldered in pins so the screen can be remotely mounted and I've added those heatsinks myself for cooling :)

I finally managed to get mine running with this firmware,  what I'd really like to do is get it running with a 1106 oled instead of the 1306 the firmware natively supports.

I want to use a 1.3" oled but can only find them in 1106 controller types :(

arvebjoe, 2019-12-01:
How did you connect this up? What are the TX\RX pins? Or did you use the SPI port (miso, mosi and sck)?

stevefoxuk, 2019-12-01:
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

If you were talking to me then yes, I soldered header pins to the spi pads and flashed it that way :)

pavel4n, 2020-03-28:
Hello,
Could anybody help?

How do you power the device?
Is it via 5V or is it possible via 12V somehow somewhere?

Where do you take video and oudio output?

Thanks.

stevefoxuk, 2020-03-28:
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

If you look at my pic in a previous post, the pins for audio and video are labled on the board.

I believe these boards can be powered on the first pin on the left with higher voltages as that pin goes to a regulator but please don't hold me too that, I have only ever powered mine with 5v via the 5v pin.

xtremcoimbra, 2021-02-13:
Hi,
Can anyone help me
I have a board that´s works well with a new 1.3 "oled sh1106, but I'm not able to compile with the oled version to get these menus:

https://github.com/sheaivey/rx5808-pro-diversity/blob/develop/docs/oled-arduino-nano.md

However if using the SSD1306 it compiles perfectly in this version.

I was grateful for the possible help

xtremcoimbra, 2021-02-13:
Resolved, This is an issue with the Dim command on sh1106. Uncomment this command everything is fine

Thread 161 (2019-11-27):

video sync loss

wleagle, 2019-11-27:
Hi, I am using this firmware on my custom rx5808 diversity. The video is fine when connecting directly to the monitor.   I want to use this in my goggle, which has a front camera and a micro minimosd. The minimOSD is used in order to report the battery voltage and rssi.  However, the OSD cannot recognize the video signal and show a black screen unless I power on the VTX. Moreover, when I switch the video signal to the front camera, and switch back to the rx5808 module, the signal lost again, and I can only bring the video back by turning off and powering on the VTX again. I guess the rx5808 module only send sync signal when receiving a new 5.8G signal, so when its video source is switched in, the OSD still use the sync signal from the last video source. If my guess is right, then how can I avoid this problem? Thank you!

wleagle, 2019-11-27:
Problem solved. I have replaced the AT7456 chip on my minimOSD with a MAX7456. Now everything's okay!

Closed 2019-11-27.

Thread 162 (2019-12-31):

Hello

gnurc, 2019-12-31:
Hello,

I have some years working in a VTX and VRX modules, this year I have assembled a VRX with high gain.

Could it be adapted to this firmware?

I am working on another similar project and I don't have much time to work on the code, besides my idea was to do something open and collaborative.

Best regards
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

JyeSmith, 2019-12-31:
Sport awesome to see someone working on an rx5808 replacement!

If you are using the same rtc7615 then your receiver module will work with this project.

I've built a module based on the ESP32 which is a fork of this repo.  Happy to test out your module if you have some samples.  Jump on my repos discord :)

https://github.com/JyeSmith/FENIX-rx5808-pro-diversity

gnurc, 2020-01-01:
Hi,

Thank you,

Yes I use several rtc integrated circuits.

I have a few assembled units, the first one I did in july. I have around 30 pcb but only a few assembled. If you send me an address I could send you one to try. Now I am doing the pcb so I hope to improve the design of the pcb and I wait to try with rf copper laminates to see if that improve something.

Also I have ic to a 2.4Ghz version if that may interested.

Awesome I don't know that exist a ESP32 port. I'm going to look it. I have not try this firmware, I have a arduino micro only not sure if works, I use kinetis or lpc ic.

Best regards and Happy new year

JyeSmith, 2020-01-01:
@gnurc jump on https://discord.gg/gG2sjjK and we can direct message each other.

What makes your module have a higher gain?  Different SAW filter?

gnurc, 2020-01-15:
Hi,

Sorry, I haven't seen the last post.

Double LNA. By the moment the SAW filter is Murata.

BR.

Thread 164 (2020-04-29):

Start-up problems ... I have no signal on the screen

juanvivo, 2020-04-29:
I have managed to assemble the complete circuit but I can't get it to work ... Mount the components on a breadboard, load the code in the arduino nano from the ide, and when feeding the circuit I don't get anything.

The status LED lights up but goes out instantly. The receiver C LED lights up and nothing else happens. I try to press the fourth button to see if I get a video signal from the menus or some other but I am not successful. I can't see anything on the screen ...

Any ideas what I may be doing wrong?

JyeSmith, 2020-04-30:
One thing you can check is if the rx5808 modules are working.  With no SPI connection they will default to A1.  Only connect power and video, then set your VTx to A1 and check for an image.  Now check the RSSI pad for a voltage change when switching the VTx between A1 and something else.

juanvivo, 2020-04-30:
okay. I will start testing as you indicate.

Shouldn't the channel search and configuration menu be shown on the screen even if the rx5808 doesn't work?

juanvivo, 2020-05-07:
Can you tell me a version of the arduino ide that does compile the code?

juanvivo, 2020-05-13:
What should happen when it is turned on for the first time?

I get video signal video signal on the monitor, A1 signal in the tx. I see the image on the monitor but I press the buttons and nothing happens ... Pressing the osd button should the configuration menus come out?

JyeSmith, 2020-05-13:
You have followed the wiring diagram from here? https://github.com/JyeSmith/FENIX-rx5808-pro-diversity/tree/quadversity

If so, after pressing the OSD button you should see the menu in your goggles in stead of video.

juanvivo, 2020-05-14:
Yes, I have made that diagram, and I have recorded the code here: https://github.com/JyeSmith/FENIX-rx5808-pro-diversity/archive/quadversity.zip

I am going to try to create a pcb board on the mill to eliminate possible connection failures on the breadboard ... Are there board files available?

JyeSmith, 2020-05-14:
No PCBs for Arduino nano or stm32f1 quadversity.  I have PCBs for the ESP32 module but I did not continue quadversity with that branch.

juanvivo, 2020-05-14:
Well I can't think of what to do to find the problem apart from making a pcb ... I've never done it, but I'll try. If you have any more ideas about what could be wrong ... I will appreciate it.

JyeSmith, 2020-05-14:
So when you press the OSD button the video stays? Or disappears? Or gets worse?

If you have discord jump in the chat linked on my repo.

juanvivo, 2020-05-14:
i have discord, but i cant see any link to your chat... I am not very familiar with the github format and I have a hard time finding information ...

JyeSmith, 2020-05-14:
https://discord.gg/gG2sjjK

juanvivo, 2020-05-14:
Solved. The problem was that the buttons were upside down ... and in this way they were always pressed ...

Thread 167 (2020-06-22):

Running the code on arduino pro mini 328p

crysis-ps, 2020-06-22:
Hello, I have a question. Could this code be working on arduino pro mini 328p 16Mhz 5V ?
Seems it has same proc - atmega 328p as on arduino nano. All required pins available.
I built the pcb board with pro mini (same as simple oled non diversity version). And trying to flash it.
But it has some problem. After flashing with arduino IDE, I get white snow screen on oled, the status led just blink once after startup. And there is no any reaction on buttons.
May be something wrong with libraries? I have latest adafruit 1306 and Gfx libraries.
(the adafruit 128-64 i2c example work fine on this board)

crysis-ps, 2020-06-24:
flash the compiled hex - and seems all working.
Now I try to find required version of libraries to successfull compiling code..

crysis-ps, 2021-02-16:
with properly versions of libraries it works fine

largrovas, 2021-11-07:
> with properly versions of libraries it works fine

For me: Adafruit_SSD1306 1.1.2 and Adafruit_GFX 1.2.3

Closed 2021-02-16.

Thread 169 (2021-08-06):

Is this still being worked on?

appkoders, 2021-08-06:
Are there plans on continuing the work on this project?

If anyone knows of a fork that added the voltage alarm please post the link or if there is a better project out there like this. I started coding on adding the voltage alarm not yet done but wanted to ask here because it is a waste of time if someone already did it.

JyeSmith, 2021-08-06:
I added voltage monitoring.  But my current fork is pretty different.

https://github.com/JyeSmith/FENIX-rx5808-pro-diversity

cad435, 2021-11-14:
I just forked and builded the project.
Switched to PlatformIO Enviroment, added code so that the beeper is beeping whenever voltage falls under 3.2V

I also added the schematic I created. It has a builtin Lithium charging circuitry with a stepup to boost the voltage to 5V.

You can find it here and start from there if interested: https://github.com/cad435/rx5808-pro-diversity

keep in mind that out of time constraints its not the tidiest project of mine tbf...

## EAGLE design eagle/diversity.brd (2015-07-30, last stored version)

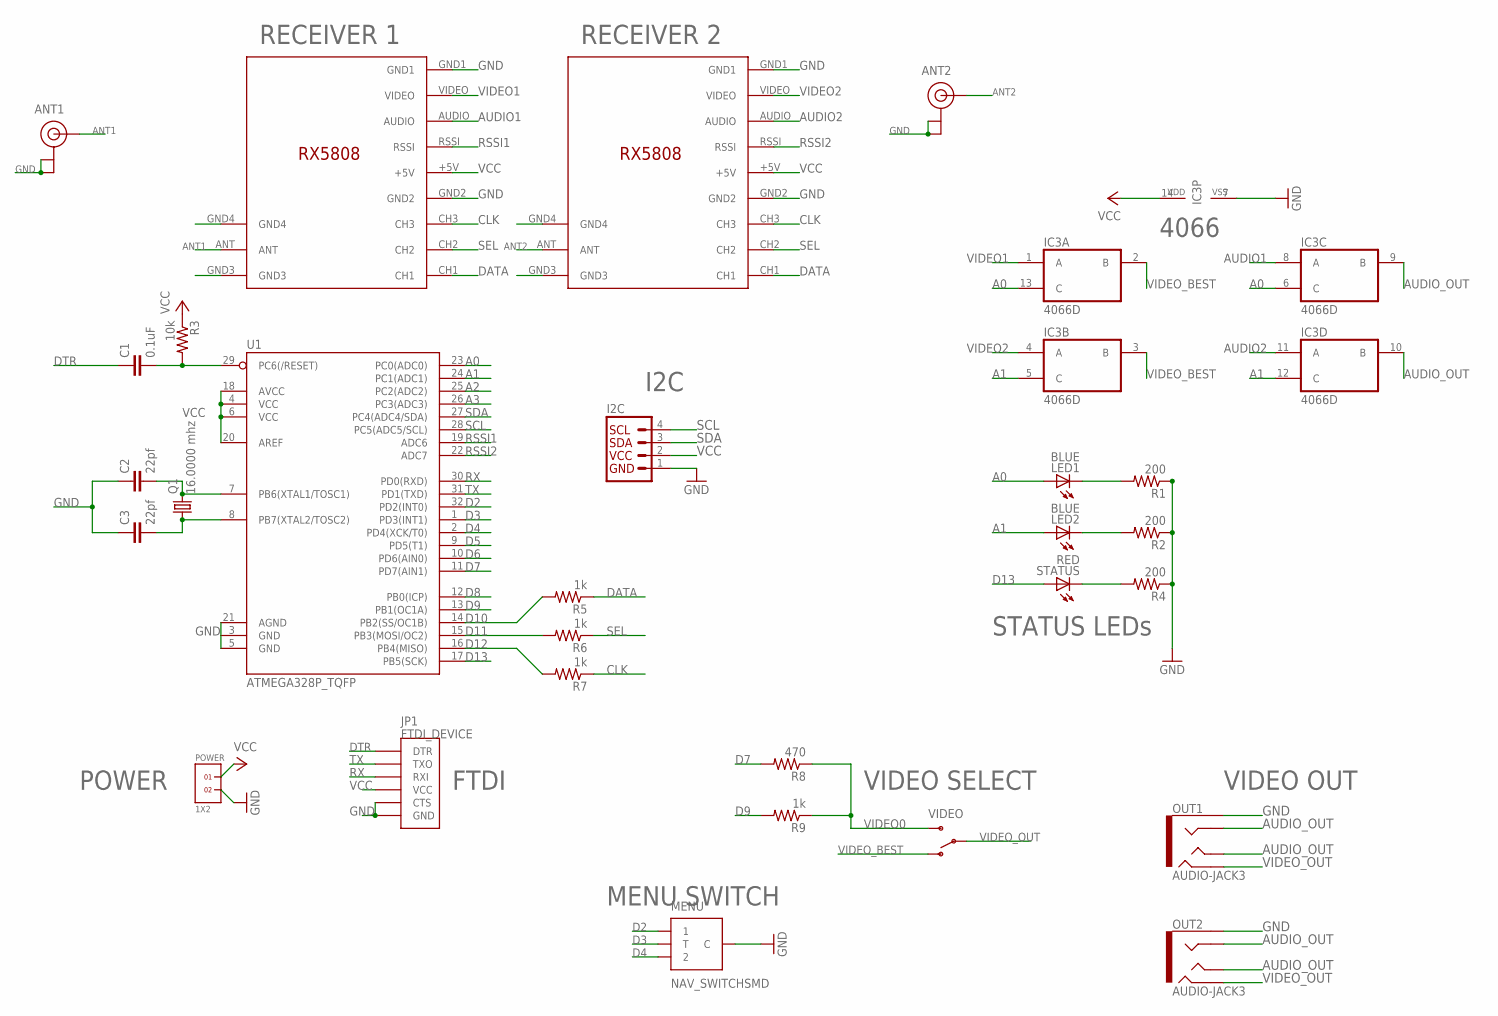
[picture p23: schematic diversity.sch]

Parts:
ANT1, ANT2: U.FL
C1: 0.1uF; 0603-CAP
C2, C3: 22pf; 0603-CAP
I2C: I2C_STANDARD; 1X04
IC3: 4066D; SO14
JP1: FTDI_DEVICE; FTDI_DEVICE_SIDE
LED1, LED2: BLUE; SML0603
MENU: NAV_SWITCHSMD; NAV_SWITCH
OUT1, OUT2: AUDIO-JACK3; AUDIO-JACK-TRRS-SMD
POWER: 1X2
Q1: 16.0000 mhz; HC49U-V
R1, R2, R4: 200; R0603
R3: 10k; R0603
R5, R6, R7, R9: 1k; R0603
R8: 470; R0603
RECEIVER_A: RX5808_A; RX5808
RECEIVER_B: RX5808_B; RX5808
STATUS: RED; SML0603
U1: ATMEGA328P_TQFP; TQFP32-08
VIDEO: SWITCH-SPDTSMD2; SWITCH-SPDT-SMD

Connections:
A0: IC3.6 (C), IC3.13 (C), LED1.A, U1.23 (PC0(ADC0))
A1: IC3.5 (C), IC3.12 (C), LED2.A, U1.24 (PC1(ADC1))
A2: U1.25 (PC2(ADC2))
A3: U1.26 (PC3(ADC3))
ANT1: ANT1.P$3 (SIGNAL), RECEIVER_A.ANT
ANT2: ANT2.P$3 (SIGNAL), RECEIVER_B.ANT
AUDIO1: IC3.8 (A), RECEIVER_A.AUDIO
AUDIO2: IC3.11 (A), RECEIVER_B.AUDIO
AUDIO_OUT: IC3.9 (B), IC3.10 (B), OUT1.RING1, OUT1.TIP, OUT2.RING1, OUT2.TIP
CLK: R7.1, RECEIVER_A.CH3, RECEIVER_B.CH3
D2: MENU.1, U1.32 (PD2(INT0))
D3: MENU.T, U1.1 (PD3(INT1))
D4: MENU.2, U1.2 (PD4(XCK/T0))
D5: U1.9 (PD5(T1))
D6: U1.10 (PD6(AIN0))
D7: R8.2, U1.11 (PD7(AIN1))
D8: U1.12 (PB0(ICP))
D9: R9.2, U1.13 (PB1(OC1A))
D10: R5.2, U1.14 (PB2(SS/OC1B))
D11: R6.2, U1.15 (PB3(MOSI/OC2))
D12: R7.2, U1.16 (PB4(MISO))
D13: STATUS.A, U1.17 (PB5(SCK))
DATA: R5.1, RECEIVER_A.CH1, RECEIVER_B.CH1
DTR: C1.1, JP1.P$1 (DTR)
GND: ANT1.P$1 (GND), ANT1.P$2 (GND), ANT2.P$1 (GND), ANT2.P$2 (GND), C2.1, C3.1, I2C.1, IC3.7 (VSS), JP1.P$5 (CTS), JP1.P$6 (GND), MENU.C, OUT1.EARTH, OUT2.EARTH, POWER.2, R1.1, R2.1, R4.1, RECEIVER_A.GND1, RECEIVER_A.GND2, RECEIVER_A.GND3, RECEIVER_A.GND4, RECEIVER_B.GND1, RECEIVER_B.GND2, RECEIVER_B.GND3, RECEIVER_B.GND4, U1.5 (GND), U1.21 (AGND)
unnamed: LED1.C, R1.2
unnamed: LED2.C, R2.2
unnamed: C2.2, Q1.2, U1.7 (PB6(XTAL1/TOSC1))
unnamed: C1.2, R3.2, U1.29 (PC6(/RESET))
unnamed: C3.2, Q1.1, U1.8 (PB7(XTAL2/TOSC2))
unnamed: R4.2, STATUS.C
RSSI1: RECEIVER_A.RSSI, U1.19 (ADC6)
RSSI2: RECEIVER_B.RSSI, U1.22 (ADC7)
RX: JP1.P$3 (RXI), U1.30 (PD0(RXD))
SCL: I2C.4, U1.28 (PC5(ADC5/SCL))
SDA: I2C.3, U1.27 (PC4(ADC4/SDA))
SEL: R6.1, RECEIVER_A.CH2, RECEIVER_B.CH2
TX: JP1.P$2 (TXO), U1.31 (PD1(TXD))
VCC: I2C.2, IC3.14 (VDD), JP1.P$4 (VCC), POWER.1, R3.1, RECEIVER_A.+5V, RECEIVER_B.+5V, U1.4 (VCC), U1.6 (VCC), U1.18 (AVCC), U1.20 (AREF)
VIDEO0: R8.1, R9.1, VIDEO.3 (S)
VIDEO1: IC3.1 (A), RECEIVER_A.VIDEO
VIDEO2: IC3.4 (A), RECEIVER_B.VIDEO
VIDEO_BEST: IC3.2 (B), IC3.3 (B), VIDEO.1 (O)
VIDEO_OUT: OUT1.RING2, OUT2.RING2, VIDEO.2

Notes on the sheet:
POWER
FTDI
RECEIVER 1
RECEIVER 2
4066
STATUS LEDs
I2C
MENU SWITCH
VIDEO OUT
VIDEO SELECT

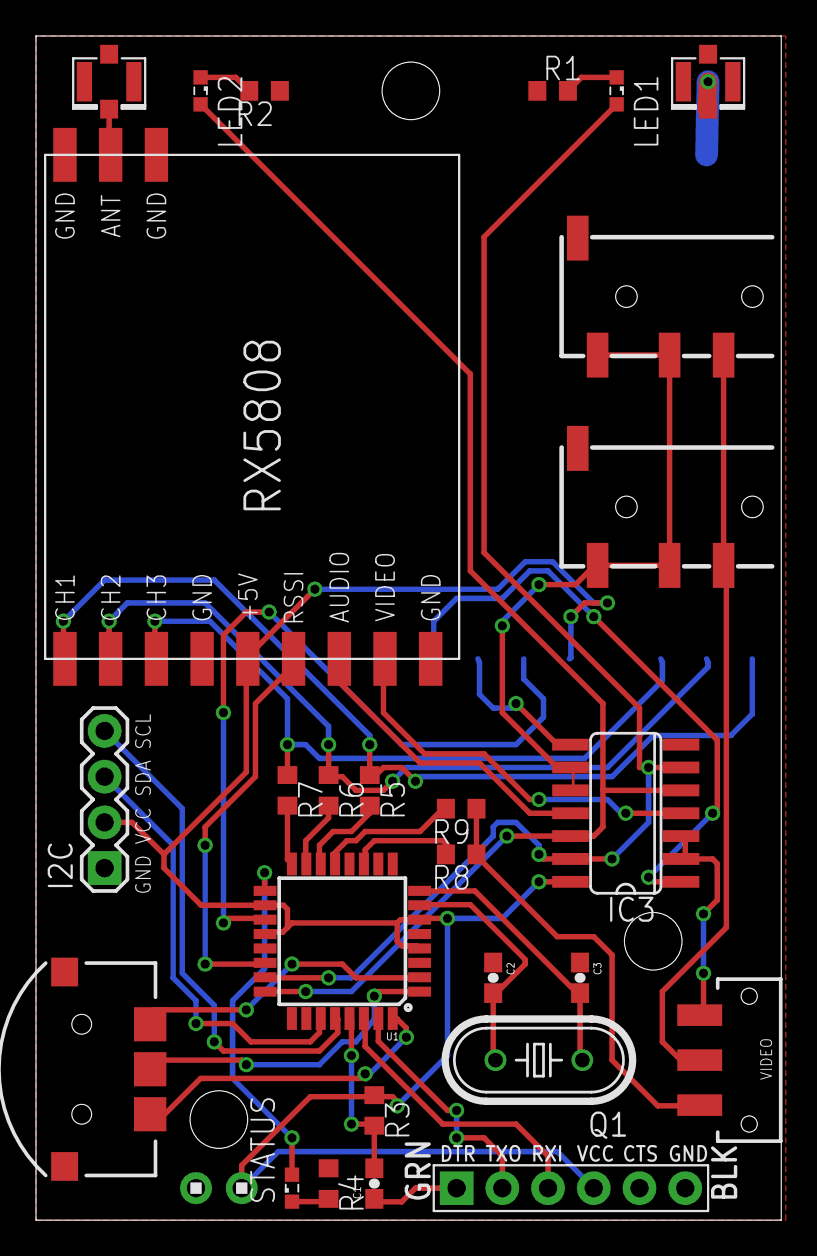
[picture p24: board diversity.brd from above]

Board: 2 copper layers, 41.4 x 65.8 mm, 29 parts (1 on the bottom side), 39 nets.

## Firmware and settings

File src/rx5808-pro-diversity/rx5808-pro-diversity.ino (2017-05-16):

/*
 * SPI driver based on fs_skyrf_58g-main.c Written by Simon Chambers
 * TVOUT by Myles Metzel
 * Scanner by Johan Hermen
 * Inital 2 Button version by Peter (pete1990)
 * Refactored and GUI reworked by Marko Hoepken
 * Universal version my Marko Hoepken
 * Diversity Receiver Mode and GUI improvements by Shea Ivey
 * OLED Version by Shea Ivey
 * Seperating display concerns by Shea Ivey

The MIT License (MIT)

Copyright (c) 2015 Marko Hoepken

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
THE SOFTWARE IS PROVIDED "AS IS", WITHOUT WARRANTY OF ANY KIND, EXPRESS OR
IMPLIED, INCLUDING BUT NOT LIMITED TO THE WARRANTIES OF MERCHANTABILITY,
FITNESS FOR A PARTICULAR PURPOSE AND NONINFRINGEMENT. IN NO EVENT SHALL THE
AUTHORS OR COPYRIGHT HOLDERS BE LIABLE FOR ANY CLAIM, DAMAGES OR OTHER
LIABILITY, WHETHER IN AN ACTION OF CONTRACT, TORT OR OTHERWISE, ARISING FROM,
OUT OF OR IN CONNECTION WITH THE SOFTWARE OR THE USE OR OTHER DEALINGS IN THE
SOFTWARE.
*/


#include "settings.h"
#include "settings_internal.h"
#include "settings_eeprom.h"

#include "channels.h"
#include "receiver.h"
#include "receiver_spi.h"
#include "buttons.h"
#include "state.h"

#include "ui.h"


static void globalMenuButtonHandler(
    Button button,
    Buttons::PressType pressType
);


void setup()
{
    setupPins();

    // Enable buzzer and LED for duration of setup process.
    digitalWrite(PIN_LED, HIGH);
    digitalWrite(PIN_BUZZER, LOW);

    setupSettings();

    StateMachine::setup();
    Receiver::setup();
    Ui::setup();

    Receiver::setActiveReceiver(Receiver::ReceiverId::A);

    #ifdef USE_IR_EMITTER
        Serial.begin(9600);
    #endif
    #ifdef USE_SERIAL_OUT
        Serial.begin(250000);
    #endif

    // Setup complete.
    digitalWrite(PIN_LED, LOW);
    digitalWrite(PIN_BUZZER, HIGH);

    Buttons::registerChangeFunc(globalMenuButtonHandler);

    // Switch to initial state.
    StateMachine::switchState(StateMachine::State::SEARCH);
}

void setupPins() {
    pinMode(PIN_LED, OUTPUT);
    pinMode(PIN_BUZZER, OUTPUT);
    pinMode(PIN_BUTTON_UP, INPUT_PULLUP);
    pinMode(PIN_BUTTON_MODE, INPUT_PULLUP);
    pinMode(PIN_BUTTON_DOWN, INPUT_PULLUP);
    pinMode(PIN_BUTTON_SAVE, INPUT_PULLUP);

    pinMode(PIN_LED_A,OUTPUT);
    #ifdef USE_DIVERSITY
        pinMode(PIN_LED_B,OUTPUT);
    #endif

    pinMode(PIN_RSSI_A, INPUT_PULLUP);
    #ifdef USE_DIVERSITY
        pinMode(PIN_RSSI_B, INPUT_PULLUP);
    #endif

    pinMode(PIN_SPI_SLAVE_SELECT, OUTPUT);
    pinMode(PIN_SPI_DATA, OUTPUT);
	pinMode(PIN_SPI_CLOCK, OUTPUT);

    digitalWrite(PIN_SPI_SLAVE_SELECT, HIGH);
    digitalWrite(PIN_SPI_CLOCK, LOW);
    digitalWrite(PIN_SPI_DATA, LOW);
}

void setupSettings() {
    EepromSettings.load();
    Receiver::setChannel(EepromSettings.startChannel);
}


void loop() {
    Receiver::update();
    Buttons::update();
    StateMachine::update();
    Ui::update();
    EepromSettings.update();

    if (
        StateMachine::currentState != StateMachine::State::SCREENSAVER
        && StateMachine::currentState != StateMachine::State::BANDSCAN
        && (millis() - Buttons::lastChangeTime) >
            (SCREENSAVER_TIMEOUT * 1000)
    ) {
        StateMachine::switchState(StateMachine::State::SCREENSAVER);
    }
}


static void globalMenuButtonHandler(
    Button button,
    Buttons::PressType pressType
) {
    if (
        StateMachine::currentState != StateMachine::State::MENU &&
        button == Button::MODE &&
        pressType == Buttons::PressType::HOLDING
    ) {
        StateMachine::switchState(StateMachine::State::MENU);
    }
}

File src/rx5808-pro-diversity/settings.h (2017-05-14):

/*
 * Setings file by Shea Ivey

The MIT License (MIT)

Copyright (c) 2015 Shea Ivey

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
THE SOFTWARE IS PROVIDED "AS IS", WITHOUT WARRANTY OF ANY KIND, EXPRESS OR
IMPLIED, INCLUDING BUT NOT LIMITED TO THE WARRANTIES OF MERCHANTABILITY,
FITNESS FOR A PARTICULAR PURPOSE AND NONINFRINGEMENT. IN NO EVENT SHALL THE
AUTHORS OR COPYRIGHT HOLDERS BE LIABLE FOR ANY CLAIM, DAMAGES OR OTHER
LIABILITY, WHETHER IN AN ACTION OF CONTRACT, TORT OR OTHERWISE, ARISING FROM,
OUT OF OR IN CONNECTION WITH THE SOFTWARE OR THE USE OR OTHER DEALINGS IN THE
SOFTWARE.
*/

#ifndef SETTINGS_H
#define SETTINGS_H


// === Display Module ==========================================================
//
// You can choose one display module only. Only 128x64 OLED displays are
// supported.
//
// =============================================================================

// SSH1106 needs https://github.com/badzz/Adafruit_SH1106 installed.
//#define SH1106

//#define TVOUT_SCREENS
#define OLED_128x64_ADAFRUIT_SCREENS

// Enable this if your screen is upside down.
//#define USE_FLIP_SCREEN

#ifdef OLED_128x64_ADAFRUIT_SCREENS
    #define OLED_ADDRESS 0x3C // I2C address for display (0x3C or 0x3D, usually)
#endif

// === Receiver Module =========================================================
//
// Select which receiever you are using. Required for time tuning.
//
// =============================================================================

#define RX5808
//#define RX5880

// Can enable this to powerdown the audio blocks on the RX58xx if you don't
// need it. Save a tiny bit of power, make your videos less noisy.
//
// WARNING: Makes RSSI act a little weird.
//#define DISABLE_AUDIO

// === Features ===============================================================
//
// Keep in mind that there is limited program memory. Only enable the features
// you need.
//
// =============================================================================

#define USE_DIVERSITY

// Enable this to switch receivers much faster. This uses the port registers
// to switch rather than the Arduino helper functions.
//
// WARNING: You can only use this if your receivers are on the same port.
// Arduino/ATmega has 3 ports: PORTD, PORTB, and PORTC. The "default" hardware
// configuration uses pins A0 and A1 (PORTC), so if you're using reasonably
// standard hardware then this should be fine.
//
// PORTC: Pins A0-A7
// PORTD: 0-7
// PORTB: 8-13
#define USE_DIVERSITY_FAST_SWITCHING

//#define USE_IR_EMITTER
//#define USE_SERIAL_OUT // Not compatible with IR emitter.

// You can use any of the arduino analog pins to measure the voltage of the
// battery. See additional configuration below.
//#define USE_VOLTAGE_MONITORING

// Choose if you wish to use 8 additional channels:
//     5362 MHz
//     5399 MHz
//     5436 MHz
//     5473 MHz
//     5510 MHz
//     5547 MHz
//     5584 MHz
//     5621 MHz
// Local laws may prohibit the use of these frequencies so use at your own risk!
#define USE_LBAND

// === Pins ====================================================================

// Buttons (required)
#define PIN_BUTTON_UP 2
#define PIN_BUTTON_MODE 3

// Buttons (optional, for comfort)
#define PIN_BUTTON_DOWN 4
#define PIN_BUTTON_SAVE 5

#define PIN_LED 13
#define PIN_BUZZER 6 // Must be an active buzzer, not passive.

#define PIN_SPI_DATA 10
#define PIN_SPI_SLAVE_SELECT 11
#define PIN_SPI_CLOCK 12

#define PIN_RSSI_A A6
#define PIN_LED_A A0
#ifdef USE_DIVERSITY
    #define PIN_LED_B A1
    #define PIN_RSSI_B A7
#endif

#ifdef USE_VOLTAGE_MONITORING
    #ifdef TVOUT_SCREENS
        #define PIN_VBAT A4
    #else
        #define PIN_VBAT A2
    #endif
#endif

// === Diversity ===============================================================

#ifdef USE_DIVERSITY
    // RSSI strength should be greater than the value below (percent) over the
    // other receiver before we switch. This pervents flicker when RSSI values
    // are close and delays diversity checks counter.
    #define DIVERSITY_HYSTERESIS 2

    // How long (ms) the RSSI strength has to have a greater difference than the
    // above before switching.
    #define DIVERSITY_HYSTERESIS_PERIOD 5
#endif

// === Voltage Monitoring ======================================================
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

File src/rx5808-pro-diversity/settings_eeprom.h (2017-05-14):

#ifndef EEPROM_SETTINGS_H
#define EEPROM_SETTINGS_H


#include <stdint.h>
#include <avr/pgmspace.h>

#include "settings.h"
#include "settings_internal.h"
#include "receiver.h"


struct EepromSettings {
    uint32_t magic;
    uint8_t startChannel;

    uint8_t beepEnabled;

    uint8_t searchManual;
    uint8_t searchOrderByChannel;

    uint16_t rssiAMin;
    uint16_t rssiAMax;

    #ifdef USE_DIVERSITY
        Receiver::DiversityMode diversityMode;
        uint16_t rssiBMin;
        uint16_t rssiBMax;
    #endif

    #ifdef USE_VOLTAGE_MONITORING
        uint8_t vbatScale;
        uint8_t vbatWarning;
        uint8_t vbatCritical;
    #endif


    void update();

    void load();
    void save();
    void markDirty();

    void initDefaults();
};


PROGMEM const struct {
    uint32_t magic = EEPROM_MAGIC;
    uint8_t startChannel = 0;

    uint8_t beepEnabled = true;

    uint8_t searchManual = false;
    uint8_t searchOrderByChannel = false;

    uint16_t rssiAMin = RSSI_MIN_VAL;
    uint16_t rssiAMax = RSSI_MAX_VAL;

    #ifdef USE_DIVERSITY
        Receiver::DiversityMode diversityMode = Receiver::DiversityMode::AUTO;
        uint16_t rssiBMin = RSSI_MIN_VAL;
        uint16_t rssiBMax = RSSI_MAX_VAL;
    #endif

    #ifdef USE_VOLTAGE_MONITORING
        uint8_t vbatScale = VBAT_SCALE;
        uint8_t vbatWarning = WARNING_VOLTAGE;
        uint8_t vbatCritical = CRITICAL_VOLTAGE;
    #endif
} EepromDefaults;


extern EepromSettings EepromSettings;


#endif

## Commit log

2015-07-30 Adding initial Eagle files to project.
    [diversity.brd, diversity.sch]
2015-07-30 Adding initial enclosure to project.
    [enclosure.skp, enclosure~.skp]
2015-07-30 Adding feature toggles for USE_DIP and USE_DIVERSITY Adding Diversity setting to EEPROM Creating Diversity menu for selecting receivers. Removing experimental code for video overlay. Adding mode quic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
2015-07-30 Removing temp files. adding enclosure make files.
    [enclosure-lines.dxf, enclosure-wall.stl, enclosure~.skp]
2015-08-01 Changing mode select to use Seek and down buttons and mode for select. Remember last mode selected. Adding RSSI A/B to diversity screen.
2015-08-03 Adding diversity rss calibration for receiver b.
2015-08-10 adding enclosure images.
2015-08-11 Adding missing pin numbers to 4066 chip.
2015-08-16 Adding backward compatible schematic.
2015-08-18 Adding optional flag to BOM.
2015-08-30 Adding OLED documentation and schematics.
2015-09-01 Simplifying diversity switching so it is less confusing to step through.
2015-09-02 adding compile error when trying to use an incorrect OLED screen size. Currently only supports 128x64.
    [rx5808-pro-diversity.ino]
2015-09-02 removing unnecessary files from project. Will replace with OSH Park open hardware links.
    [diversity.brd, diversity.sch, enclosure-lines.dxf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]
2015-09-03 Fixing a pretty substantial bug in the diversity RSSI read. Copy and past error :(
    [rx5808-pro-diversity.ino]
2015-09-05 Removing slight flicker when switching antennas.
2015-09-07 Making it so you can seek in both directions depending on button pressed.
2015-09-09 updating custom board documentation.
2015-09-09 Updating custom board images.
2015-09-10 Adding optional I2C and Buzzer to the board.
2015-09-12 Fixes errors when not in diversity mode
    [rx5808-pro-diversity.ino]
2015-09-13 Cleaning up error when not using diversity.
    [rx5808-pro-diversity.ino]
2015-09-14 finalizing how screens get swapped.
    [settings.h]
2015-10-05 adding pull down resistor to RSSI
2015-10-22 Fix for the following issue #43
    [rx5808-pro-diversity.ino]
2015-10-23 Update to diy-through-hole-board.md
2015-10-23 Update to diy-through-hole-boardv1.1.md
2015-10-25 Update to button info.
2015-10-26 Revert "Update to diy-through-hole-boardv1.1.md"
    This reverts commit ffe85fbc083b51d936229bd0ebec730301b6fc76.
2015-10-26 Updated images for diy-through-hole-board.md
2015-10-27 Adding recognision to RCDaddy for his through hole version of the board.
2015-10-27 updating documentation and images for SPI programable board.
2015-10-27 adding link to through hole version.
2015-10-27 Update diy-through-hole-board.md
    Added code change for atmega328p.
2015-11-03 fixing up/down menu interactions.
    [rx5808-pro-diversity.ino]
2015-11-08 Adding the optional IR emitter to all schematics.
2015-11-16 Adding donation button.
2015-11-21 Update diy-through-hole-board.md
    Updated OSHPark link for v1.1 to revi 2
2015-12-24 fix bug when USE_DIVERSITY is disabled.
    [rx5808-pro-diversity.ino]
2015-12-24 prevent blink after boot screens.
    [rx5808-pro-diversity.ino]
2015-12-28 Updating calibration steps.
2015-12-29 Fix for constrained RSSI readings before being used to compare best diversity module.
    [rx5808-pro-diversity.ino]
2015-12-29 Now that we can potentially have negative numbers we need to switch to signed integers.
2016-01-13 adding check to set calibration back to default when no VTX is present.
2016-02-26 Add Mouser links for most BOM items.
2016-04-15 update mouser urls in custom board
2016-08-01 Fix for Raceband 5
    Update for the channelTable for raceband 5
    [rx5808-pro-diversity.ino]
2016-10-13 When USE_DIVERSITY is disabled when menu_id==3 back up two menu slots
2016-11-16 Add battery voltage monitoring.
    Menu only exists for TVout screen as this is the onlky one i have
2016-11-16 add the screens only when voltage feature toggle is defined
2016-11-16 add voltage monitoring to oled, use A2 by default
2016-11-16 fix schematic image
2016-11-17 fix swapping buttons when editing thx @error414
    [rx5808-pro-diversity.ino]
2016-11-20 dont use DELAY when using the voltage alarm, add options to customize alarm sounds
    fix menu traverse in voltage menu
    [rx5808-pro-diversity.ino, settings.h]
2016-11-20 flash the voltage on screensaver(oled) when an alarm is in progress
2016-12-22 Revert "Use common file define convention"
    This reverts commit dec95bd743d017dfcde5f030863e6efae33f6a3d.
    [settings.h]
2016-12-22 Use Arduino style include-guards, but in caps
2016-12-22 Move OLED reset pin to internal settings
2016-12-22 Drop SPI/Wire includes (handled by Adafruit libs)
2016-12-22 Standardise pin defines
2016-12-22 Drop OLED pin (unused) + misc comment fixes
    [settings.h]
2016-12-22 Move receiver SPI functions to seperate file
2016-12-22 Simplify SPI command sending.
    - Added documentation explaining what's going on.
    - Use inline functions for a miniscule speedup.
    - General tidy up.
    - Drop commands/bits that don't seem to do anything (may be in
    the wrong here but it doesn't affect my module!)
2016-12-22 Misc. tidy up.
    - Make beep function more clearer
    - Fix naming convention on helper functions.
    [rx5808-pro-diversity.ino]
2016-12-22 Move receiver switching to their own files
2016-12-22 Enable pull-up resistors on RSSI pins
2016-12-22 Some helpers for button state and bebouncing (yet unused)
2016-12-22 Use enums for button state tracking
    - Also add wait for release func.
    - Not too sure about all this, feels a little "off"
2016-12-22 Lightly integrate button state where possible
    Only really one place it can be without changing main loop logic.
2016-12-22 Fix function name for voltage alarm
    [rx5808-pro-diversity.ino]
2016-12-22 Use namespaces for button state handler
    Who would have thought it was a good idea to put enum literals
    in the same namespace as where you define the namespace?
2016-12-22 Revert "Move settings code into a folder"
    Having issues with .cpp files in folders rather than in the root
    source folder. Will fix later on.
    [rx5808-pro-diversity.ino, settings.h]
2016-12-22 Break receiver SPI commands out to seperate file
2016-12-23 Add button func for checking if any button is pressed.
    - Also some misc tidy up
2016-12-23 Super basic tests of switching state
2016-12-23 Track last state in state machine
2016-12-23 Switch to previous state after screensaver button
2016-12-23 Simplify button debounce a little
    - Make use of shortcutting to avoid millis() call
    - Set state /inside/ update func using reference, little gross but
    seems cleaner in this case.
2016-12-23 Get manual scan working with new state machine
    Little broken at the moment (due to straight checks on button per
    tick rather than one trigger per one up push)
    [rx5808-pro-diversity.ino]
2016-12-23 Add support for button change hooks
2016-12-23 Fix button presses on manual mode state
    [rx5808-pro-diversity.ino]
2016-12-27 Rename headers to be category first
    At least, until fixed to be organised into directories
    [receiver.cpp, rx5808-pro-diversity.ino, settings_eeprom.h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]
2017-01-29 Fix crash on boot due to typos!
    [rx5808-pro-diversity.ino, settings.h]
2017-02-17 Lower button hook count
2017-02-17 Track previous RSSI values
2017-02-17 Add framerate limiter
2017-02-17 Drop analog pull-ups and set RSSI pin mode.
2017-02-17 Use long for framerate counter
2017-02-19 Disable audio power-off by default since it breaks RSSI reads
2017-02-22 Provide button change as a state member func
2017-02-22 Simplify button state somewhat
2017-02-23 Add RSSI calibration
2017-02-24 Add timer helper
2017-03-10 Fix broken pin mode settings + use RSSI pullup again
    [rx5808-pro-diversity.ino]
2017-03-25 Improve diversity switching logic
2017-03-25 Implement fast switching from #98
2017-03-25 Use timer helper for screensaver swap
2017-03-25 Fix broken stuff for non-diversity users
    [receiver.cpp, settings.h]
2017-03-26 Fix dumb typos that break diversity
    [receiver.cpp, settings_eeprom.h]
2017-04-10 Invert buzzer logic so it stops beeping all the time
    [rx5808-pro-diversity.ino]
2017-04-10 First pass at abstracting different types of button presses (long, short, holding, etc)
    [rx5808-pro-diversity.ino]
2017-04-17 Tidy up search state buttons a little bit
2017-04-17 Drop unnecessary wait in search, bump up framerate, reduce animation steps
2017-04-29 Memoize ticked in timer to stop repeated calls to millis()
2017-05-06 Increase PSTR2 buffer (fix broken calibration)
    - No idea how this didn't cause problems before. Luck?
2017-05-15 swap RRSI A and B graph to match physical connectors

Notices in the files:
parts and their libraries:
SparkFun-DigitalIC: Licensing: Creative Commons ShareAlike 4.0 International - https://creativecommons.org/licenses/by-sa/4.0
